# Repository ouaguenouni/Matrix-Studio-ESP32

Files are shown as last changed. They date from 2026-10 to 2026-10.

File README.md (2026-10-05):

# Matrix Studio: ESP32 + Waveshare 64x32

A local browser interface hosted on your ESP32. Send text, resized still images,
pixel drawings, animated GIFs, or browser-streamed scrolling text
to the panel. No cloud account
or separate server is needed. Upload this firmware once; ordinary display updates
then happen over Wi-Fi. Pokémon sprites, the Crystal GIF gallery, cries, and
Bluetooth audio live on the `pokemon` branch.

The five 3D enclosure designs are in
[`cad/enclosure-comparison`](cad/enclosure-comparison/README.md), with an offline
3D viewer, individual STL kits and assembly guides. Digital geometry checks pass;
fit with the actual components still needs a workshop test.

A simpler [two-part frame with an enclosed rear](cad/minimal-frame/README.md)
adds integral ESP32 guides and rear-facing USB-C/DC access. Its
[French workshop guide](cad/minimal-frame/FABLAB-FR.md) covers fit checks and assembly.

## Your hardware

- Classic ESP32-WROOM development board, configured as **esp32dev** in PlatformIO.
- One Waveshare HUB75 panel, 64x32, using the FM6124 driver. The earlier close-up
  appeared to show FM6124H chips. If a previous test sketch works with another driver
  or a different clock phase, carry those settings into `src/main.cpp`.
- Panel powered separately from a regulated 5 V supply with adequate current.
- ESP32 powered by computer USB while uploading; keep its external 5V pin unconnected
  during USB power. Panel and ESP32 grounds must be connected.
- Home Wi-Fi must offer **2.4 GHz**. Your computer/phone can use 5 GHz on the same
  router if the router allows communication between those devices.

This implementation compiles successfully with PlatformIO for **esp32dev** and
passes host-side frame-protocol tests, colour-conversion tests, and JavaScript/Python
syntax checks. USB firmware upload, Wi-Fi provisioning, reconnection, and serial
diagnostic controls have been verified on the connected ESP32. Panel timing is
being compared visually on hardware; the remaining text ghosting is unresolved.
The browser interaction tests pass against simulated endpoints in local Chromium.
Physical colour appearance still needs the viewer's confirmation.

## 1. Install and upload

1. Open this project's root folder in VS Code with the **PlatformIO IDE** extension,
   or use the PlatformIO Core CLI from this folder.
2. Connect the ESP32 by USB. `platformio.ini` selects **esp32dev**, the Arduino
   framework, and pinned versions of the ESP32 platform and display libraries.
   PlatformIO downloads dependencies automatically on the first build.
   `WiFi`, `WebServer`, `Preferences`, and `ESPmDNS` come with the framework.
3. Use PlatformIO's **Build**, **Upload**, and **Monitor** buttons, or run:

   ```bash
   pio run
   pio run --target upload
   pio device monitor
   ```

4. If multiple USB serial devices are connected, select the ESP32 explicitly with
   `pio run --target upload --upload-port /dev/cu.YOUR_PORT` and
   `pio device monitor --port /dev/cu.YOUR_PORT` (use the appropriate port on your OS).
   Run `pio device list` to see available ports.
5. If uploading waits at “Connecting…”, hold BOOT until writing starts, then release it.
6. The serial monitor uses **115200 baud**. Press the board's **EN/RST** button
   to view startup messages.

Hardware and HTTP handling live in `src/main.cpp`; live data and the background
network worker live in `src/live.cpp`. Host-testable parsing, state, and display
rendering live in `include/LiveData.h`, `LiveState.h`, and `Display.h`.
`web/display.json` is the shared font/palette source; `tools/build_display.py`
generates the C++ and JavaScript data tables as part of UI generation. The build regenerates `include/web_ui.h` and `web/preview.html` from the editable
HTML, JavaScript modules, shared display data, and bundled GIF decoder, using
PlatformIO's own Python interpreter.

## 2. Join your home Wi-Fi

On the first boot, Serial Monitor prints something like:

```text
Network: Matrix-a1b2c3
Password: <your device's generated setup password>
Open http://192.168.4.1
```

1. On your phone or computer, join that **Matrix-xxxxxx** Wi-Fi network using the
   printed password. Stay connected even if your phone says “No internet”.
2. Manually open **http://192.168.4.1** in your browser. This is a direct web page,
   not an automatic captive portal.
3. Expand **Wi-Fi connection** if necessary. Enter your home network name and password.
   Use a normal personal/password-based network; enterprise sign-in and captive
   portals are not supported by this starter.
4. Click **Save and connect**. The page and Serial Monitor show the home-network IP.
5. Rejoin your home Wi-Fi and open that IP, such as `http://192.168.1.42`.
   You can also try the unique `.local` hostname printed by Serial Monitor.

Credentials are stored on the ESP32 and reused after restart. They are not placed
in this project or returned by the status API. On the setup session the temporary
network stays active, so you can recover from a mistyped password. It will not be
started on the next boot if the saved home-network connection succeeds within
20 seconds. If joining fails, setup mode returns with the same generated password.

The IP can change after a router restart. Use the `.local` name, check Serial
Monitor, or reserve an IP for the ESP32 in your router. `.local` support varies
by device and network. Guest Wi-Fi/client isolation may block access.

## 3. Use the interface

- **Text:** multiline text, font, pixel size, alignment, foreground/background colours.
  Text is rendered by your browser, including accents supported by its fonts.
  The default is pure white on black with **Sharp text pixels** enabled. Sharp
  mode uses full foreground/background pixels instead of dim antialiased edges,
  including during scrolling. Uncheck it to keep smooth edges.
  The preview shows clipping at the actual 64x32 resolution.
- **Image:** local PNG, JPEG, WebP, BMP, or animated GIF; fit, crop, or stretch.
  Images are resized on your phone/computer, then sent as 4096-byte pixel frames.
  GIFs animate in the preview. Click **Play GIF on panel** to stream the animation,
  or **Send to display** to send a still frame. Playback loops while the page stays
  visible; Stop, Clear, or switching tabs stops uploads.
  The browser decodes transparency, frame disposal and delays, then sends one frame
  at a time. Frame delays have a 40 ms minimum.
- **Draw:** tap or drag on the preview to paint pixels; use the eraser as needed.
- **Global display palette:** Classic, Amber, Neon, Ocean, Mint, or Sunset. Each
  live mode can follow global or use its own palette. Layout and animation are
  separate settings, saved on the ESP32; changing a clock override affects only
  the clock. Text, images, drawings, and GIFs retain their own colours.
- **Weather:** animated icon/temperature or compact temperature/condition/city.
  Choose network location or search for a city. Real zero temperatures remain
  valid; missing data shows `--`. Long city names scroll slowly.
- **BOOT button:** a short press steps through clock, weather, and configured
  YouTube. EN/RST still restarts the board.
- **Clock:** large digits with a seconds indicator, or time and date, using French
  network time. Unsynchronised time shows `--:--`.
- **YouTube:** Cosmic Hippo Sounds subscribers, total views, and video count.
  Choose rotating statistics (one card every five seconds) or subscriber focus.
  Enable YouTube Data API v3 in Google Cloud and save a key on the panel. Website
  referrer restrictions do not work with direct ESP32 requests. You may restrict
  API access to YouTube Data API v3. A key in gitignored `config.conf`
  (`youtube_api_key=...`) seeds the device only when no key is already saved.
- **Animation:** Full, Subtle (default), or Off for each live mode. Off stops
  decorative motion and label scrolling, while measurements, time, and rotating
  statistic cards still update. Browser reduced-motion preference disables
  preview animation without changing the panel setting.
- **Startup and refresh:** restores the last selected live mode, including an
  explicit stopped mode, and all appearance settings. Weather and configured
  YouTube data load once Wi-Fi connects, even while the clock is showing. Refresh
  happens every ten minutes, with one-minute retries and manual refresh buttons.
  A background worker keeps the display, BOOT button, and web controls responsive.
- **Service status:** loading, ready, stale, unconfigured, or error, with the age of
  the last successful update and a useful error message. A small amber corner dot
  marks stale LED data. Failed refreshes retain the last successful values in RAM;
  after power loss, data must load again. Missing data shows `LOADING`, `ADD KEY`,
  or `CHECK WEB`, rather than invented zeroes.
- **Send to display:** commits the preview. Editing alone does not update the panel.
- **Clear:** clears the preview; then press Send to clear the physical panel.
- **Brightness:** changes the physical panel immediately; initial value is 30/255.
- **Scrolling:** sends approximately eight frames per second, subject to Wi-Fi speed.
  Keep the browser page visible and awake. It stops if you leave the tab or close it.

The last sent frame remains while the ESP32 is powered, even if the browser closes.
Uploaded pixel frames and brightness are **not** restored after power loss. Wi-Fi,
live mode, location, API key, and appearance settings are restored.
Videos, saved playlists, and remote control from outside your network
are extension points, not included features. This interface has no user login;
clients on the same LAN or password-protected setup network can control it.

## Pin mapping

The table records the reported ribbon-wire connections and corrected firmware
LED channels. The direct RGB test rendered red, blue, green, so firmware swaps
green and blue on both panel halves. Wire colours identify the ribbon conductors;
they do not identify LED colours.

| Wire number | Wire colour | Firmware channel/signal | ESP32 printed label |
|---|---|---|---|
| 1 | Brown — outer edge | R1 | G25 |
| 2 | Red | B1 | G26 |
| 3 | Orange | G1 | G27 |
| 4 | Yellow | GND | GND |
| 5 | Green | R2 | G14 |
| 6 | Blue | B2 | G12 |
| 7 | Purple | G2 | G13 |
| 8 | Grey | GND | GND |
| 9 | White | A | G23 |
| 10 | Black | B | G19 |
| 11 | Brown — second occurrence | C | G5 |
| 12 | Red — second occurrence | D | G17 |
| 13 | Orange — second occurrence | CLK | G16 |
| 14 | Yellow — second occurrence | LAT/STB | G4 |
| 15 | Green — second occurrence | OE | G15 |
| 16 | Blue — other outer edge | GND | GND |

The 64x32 panel does not use E. All 5 V power stays on the separate power connector;
none of the HUB75 signal wires connects to the ESP32 5V or 3V3 pins.

## Develop your own interface

The architecture is browser rendering → RGB565 frame upload → ESP32 DMA display.
You can replace the browser editor, generate a clock/dashboard elsewhere, or use
the included Python image sender without changing how the panel is wired.

| Endpoint | Method | Input | Effect |
|---|---|---|---|
| `/` | GET | None | Browser interface |
| `/api/status` | GET | None | Network, dimensions, brightness, frame count, free heap |
| `/api/frame` | POST | One multipart file named `frame` | Atomically replace all pixels |
| `/api/brightness` | POST | URL-encoded `value=0..255` | Set brightness |
| `/api/wifi` | POST | URL-encoded `ssid` and `password` | Save credentials and connect |
| `/api/live` | POST | URL-encoded fields below | Live modes, saved appearance, and refresh |

Live control fields (all optional, validated before applying):

- `mode=clock|weather|youtube|off|save`: select a mode, freeze the current frame,
  or save settings without switching. Omitting mode also leaves it unchanged.
- `theme=classic|amber|neon|ocean|mint|sunset`: global palette. The legacy `theme`
  field remains supported. The previous saved numeric theme migrates automatically.
- `target=clock|weather|youtube` with `palette=global|<palette>`,
  `layout=large|date` (clock), `icon|detail` (weather), or `rotate|subscribers`
  (YouTube), and/or `motion=off|subtle|full`: independent per-mode appearance.
- `city=<name>` or `locate=1`: queue location lookup and weather refresh. Lookup
  completion and errors appear in status; HTTP success means accepted, not fetched.
- `key=<YouTube API key>`: persist a key and load statistics; keys are never returned.
- `refresh=weather|youtube`: request a refresh without changing the display mode.

`/api/status` keeps existing fields and adds `appearance` (`global`, plus a
`palette`, `layout`, and `motion` object per live mode), `savedMode`, `clockSynced`,
`liveTick` (milliseconds since mode selection), and `services.weather` /
`services.youtube`. Each service reports `state`, `refreshing`, `ageSeconds`
(null before first success), and `message`. Existing `temp`, `kind`, `channel`,
`subs`, `views`, and `videos` appear only after successful validated responses.
`weatherCode` contains the validated WMO code. Counts remain formatted strings;
hidden subscribers use `--`. `youtube` means a key is configured, not that a fetch
has succeeded. `live` reports `off` when manual frame uploads hold live rendering.

All POST requests require the header `X-Matrix-Control: 1`. It limits accidental
cross-site browser requests; it is **not** an authentication credential. CORS is
not enabled. Serve browser extensions from this device's page or use a backend
proxy on your own application when hosting an interface separately.

Frame format: exactly **4096 bytes**, 64x32 pixels in row order, top-left first.
Each pixel is RGB565 with the low byte first: red uses bits 11–15, green 5–10,
blue 0–4. Incomplete/oversized uploads are rejected without replacing the display.

```bash
curl -H 'X-Matrix-Control: 1' \
  -F 'frame=@frame.rgb565;type=application/octet-stream' \
  http://192.168.1.42/api/frame

curl -H 'X-Matrix-Control: 1' -d 'value=30' \
  http://192.168.1.42/api/brightness

python3 -m pip install Pillow
python3 tools/send_image.py http://192.168.1.42 photo.png
```

To edit the embedded interface, modify `web/interface.html`, `web/codec.mjs`,
`web/gif.mjs`, `web/gif-player.js`, `web/weather.mjs`, `web/clock.mjs`, or `web/youtube.mjs`,
then build and upload the firmware again. PlatformIO regenerates the embedded UI
automatically; you can also run `python3 tools/build_ui.py` manually.
`web/preview.html` is the generated UI for local inspection; a normal local preview
does not control hardware because it has no ESP32 server behind it.

## Verification and troubleshooting

After `pio run` installs pinned dependencies, run `npm run test:firmware` for
actual firmware JSON parsing, scheduling, settings migration, pixel renderer
parity (972 cases), frame protocol, and colour-table checks. Run `npm test` for
the browser and JavaScript checks.

Run `node tests/codec_test.mjs`, `node tests/modules_test.mjs`, and compile/run `tests/frame_protocol_test.cpp` with
a standard C++ compiler. `tests/browser_test.cjs` runs the browser interface
against simulated endpoints using Playwright. These do not replace hardware testing.
The small MIT-licensed omggif decoder is bundled locally with its license retained
in `web/vendor/`.

The panel runs at six-bit colour depth. `platformio.ini` also defines
`PIXEL_COLOR_DEPTH_BITS=6` when compiling the HUB75 library, so its brightness
lookup table matches the six DMA bitplanes. An eight-bit table with only six
bitplanes discards the upper bits and wraps intermediate colours; full white
can still look correct. The firmware checks the configured depth at compile time.
The regression test exercises the pinned library's actual table:

```bash
c++ -std=c++11 -Wall -Wextra -Werror -DPIXEL_COLOR_DEPTH_BITS=6 \
  -I '.pio/libdeps/esp32dev/ESP32 HUB75 LED MATRIX PANEL DMA Display/src' \
  tests/panel_colour_test.cpp -o /tmp/matrix-panel-colour-test
/tmp/matrix-panel-colour-test
```

On hardware, first verify the previous RGB test sketch works. After uploading
this project, use **Image → Preview a colour test → Send to display**. Then verify
text, brightness, Wi-Fi reconnect after a reset, and preservation of the last frame
after closing your browser. Send at low brightness for the first tests.

To bypass browser rendering and frame uploads, open the serial monitor at 115200
baud and send uppercase `T`. The firmware displays red, green, and blue vertical
bands on the top 24 rows, with a white strip on the bottom 8 rows, using RGB888
directly. Send normal content from the web
interface to replace the test. If green and blue are black in this test too, check
the corresponding signal wires and panel hardware: G1 → GPIO27, B1 → GPIO26,
G2 → GPIO13, B2 → GPIO12. Turn off power before reseating wires.

Send uppercase `W` over serial to fill the entire panel with white at the current
brightness. Send normal content from the web interface to replace the white test.
Send uppercase `G` for eight grayscale swatches from black to white on the top
half and cream, pale yellow/red/green/blue/cyan/magenta, and white on the bottom.
This uses direct RGB888 values to check intermediate shades independently of
browser resizing and RGB565 conversion. Judge the colours directly: camera
exposure timing can introduce tints or bands when photographing scanned LEDs.
Send uppercase `V` for red, green, blue, magenta, purple, dark purple, lavender,
and white columns. The top half uses direct RGB888, the bottom RGB565 as used
by browser uploads. Magenta, purple and dark purple have zero green input.
In the browser's Image tab, **Preview a purple test → Send to display** sends
the same colours through the actual browser/upload path. Compare directly with
your eyes. Differences between panel halves can also indicate separate upper
and lower signal wiring, so they are not proof of an encoding fault by themselves.
Send uppercase `H` for a static white `Hello` on a black background. This is drawn
once using the on-device font, without browser rendering or continuous frame uploads.
Startup now uses profile **N**, the best of the latest visual comparison: 4 MHz,
clock phase false, four blanking clocks, and the weakest clock drive (level 0).
Other panel signals retain the library's drive level 3. The observed ranking was
K, then I; L and M were clearly worse. N subsequently looked best when compared
with K, O and P, and remained best against the slower Q, R and S trials. N is the
selected operating setting; complete removal of shifted ghosting is unconfirmed.
Send uppercase `C` over serial to switch between clock drive levels 0 and 3 while
the same image stays displayed. Reboot restores profile N.

Send uppercase `S` to compare timing profiles A–S. Each profile displays its letter,
two white `Hello` lines, and a thin vertical white line for 12 seconds; the sequence
repeats every 228 seconds. Brightness stays constant so the timing comparisons
use the same content and intensity. Ignore the brief transition between profiles.
Report the letter with the fewest ghost pixels, checking both halves of the panel.
Serial commands: `P` pauses/resumes, `N` advances, and `X` stops and restores the
settings used before the sweep. Sending normal content, changing brightness,
or using `T`, `W`, `G`, `V`, `H`, or `C` also stops the sweep and restores those settings.

Send uppercase `F` for the focused **N → Q → R → S** comparison (12 seconds per
test, 48 seconds per cycle). This retains N's weakest clock drive, phase false,
four blanking clocks and strong non-clock signals, comparing 4, 2, 1 and 0.5 MHz.
The slowest profile is eight times slower than N. These trials intentionally
lower scan refresh too; compare the shifted copies separately from whole-panel
flicker. Serial logs include estimated scan refresh, scaled from startup's DMA
calculation. The estimate is not an oscilloscope measurement.
The same pause, next, and stop controls apply.

| Test | Clock output | Clock phase | Blanking clocks | Clock drive level |
|---|---|---|---|---|
| A | 10 MHz | false | 4 | 2 (medium) |
| B | 5 MHz | false | 4 | 2 (medium) |
| C | 10 MHz | true | 4 | 2 (medium) |
| D | 5 MHz | true | 4 | 2 (medium) |
| E | 10 MHz | false | 2 | 2 (medium) |
| F | 5 MHz | false | 2 | 2 (medium) |
| G | 10 MHz | true | 2 | 2 (medium) |
| H | 5 MHz | true | 2 | 2 (medium) |
| I | 5 MHz | false | 4 | 1 (lower) |
| J | 5 MHz | false | 4 | 3 (maximum) |
| K | 5 MHz | false | 4 | 0 (weakest) |
| L | 5 MHz | false | 4 | 1 (lower) |
| M | 5 MHz | false | 4 | 1 (lower) |
| N | 4 MHz | false | 4 | 0 (weakest) |
| O | 5 MHz | true | 4 | 0 (weakest) |
| P | 4 MHz | true | 4 | 0 (weakest) |
| Q | 2 MHz | false | 4 | 0 (weakest) |
| R | 1 MHz | false | 4 | 0 (weakest) |
| S | 0.5 MHz | false | 4 | 0 (weakest) |

Profiles A–K and N–S leave non-clock signals at the library's drive level 3. L lowers only
LAT and OE to level 1; M lowers all non-clock data/address/control signals to
level 1. Each profile restores other signals explicitly so the previous profile
does not influence the next comparison. All profiles use the same brightness.

The sweep's clock-divider override targets the classic ESP32 and pinned HUB75
library. This library's nominal `HZ_8M` configuration uses an actual 10 MHz clock
on the classic ESP32 (80 MHz / divider 4 / 2). The 5 MHz profiles use divider 8;
4 MHz uses divider 10; 2, 1 and 0.5 MHz use dividers 20, 40 and 80 respectively.
The slower profiles also lower scan refresh, so report any
whole-panel flicker separately from shifted ghost pixels.
Startup applies profile N after the library initializes DMA, and its DMA refresh
calculation uses the matching 4 MHz clock. Sweep changes are temporary and do not
rewrite saved Wi-Fi credentials or the startup configuration. Reboot exits the
sweep. Profile labels describe the clock output; the calculated refresh value
describes startup profile N and is not updated by temporary sweep overrides.

- Blank panel with a reachable web page: check input connector, ground, pin mapping,
  and driver selection. Copy any successful settings from your earlier test sketch.
- Colours swapped: first confirm the wiring. Some panel variants need a software
  swap of green and blue pins, but do not change these blindly.
- Shifted pixels/ghosting: the firmware currently uses `config.clkphase = false;`,
  a 4 MHz clock, four clock cycles of latch blanking, and the weakest clock drive.
  Use the serial timing comparisons to evaluate other settings. Short, secure
  signal wires and a shared ground remain important if ghost pixels persist.
- Resets/flicker during Wi-Fi use: verify stable power and short, secure signal wires.
  Some panel variants need a proper 3.3 V to 5 V logic buffer for reliable operation.
- Panel initialization fails: read Serial Monitor, check library/board selection,
  and temporarily try `config.double_buff = false;` if memory allocation is failing
  (frame replacement may then visibly tear).
- Wi-Fi setup fails: check exact SSID/password, 2.4 GHz availability, and personal
  network security. Retry through the setup network; no new firmware upload is needed.

## References

- Espressif Wi-Fi API: https://docs.espressif.com/projects/arduino-esp32/en/latest/api/wifi.html
- Espressif WebServer example: https://github.com/espressif/arduino-esp32/tree/master/libraries/WebServer/examples/HelloServer
- HUB75 library: https://github.com/mrcodetastic/ESP32-HUB75-MatrixPanel-DMA
- Waveshare panel: https://docs.waveshare.com/RGB-Matrix-Px-64x32
- GIF decoder (MIT): https://github.com/deanm/omggif

Updated 2026-10-04. No real Wi-Fi credentials are included.

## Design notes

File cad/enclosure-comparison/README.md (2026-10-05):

# Five enclosure designs — INGE / AFTER HOURS

The five digital prototype kits are complete: editable OpenSCAD, separate STL
parts, acrylic outlines, assembled/exploded previews, an offline interactive
viewer, quantities, and assembly instructions. Revision 3, 5 October 2026.
**Physical hardware fit is still unverified.** Fit-test the small parts with the
actual panel, ESP32 and cables before printing a complete case.

Open [viewer.html](viewer.html) in a desktop browser. It works without internet;
use the five tabs, Front/Rear, Open back and Exploded controls. The viewer embeds
actual STL meshes; the panel and PCB are nominal component envelopes. Preview
LED artwork is illustrative. [comparison.png](comparison.png) shows all five.

| Design | Case width × height × depth, mm | Acrylic, mm | Cable tray height | Estimated stored cable* |
| --- | --- | --- | --- | --- |
| [Line](kits/01-line.zip) | 190 × 110 × 94.5 | Cut 164 × 84 × 1 | 14 mm | 0.2 m |
| [Orbit](kits/02-orbit.zip) | 202 × 122 × 96.5 | Cut 164 × 84 × 1 | 20 mm | 0.4 m |
| [Gallery](kits/03-gallery.zip) | 206 × 156 × 96.5 | Full 180 × 130 × 1 | 20 mm | 0.4 m |
| [Vault](kits/04-vault.zip) | 206 × 156 × 122.5 | Full 180 × 130 × 1 | 40 mm | 1.0 m |
| [Console](kits/05-console.zip) | 202 × 122 × 108.5 | Cut 164 × 84 × 1 | 30 mm | 0.8 m |

Depth includes the rear port plate, excludes screw heads and cradle lips.
Feet add 4 mm below the case; their lips extend beyond the front/rear faces.
*One bundle with 6 mm effective diameter; estimate excludes service tails and
assumes a 0.2 m oval per turn. It is a planning allowance, not a measured cable fit.
Vault has the largest wiring compartment; Line is the smallest enclosure.

The confirmed component list is **one panel, one ESP32, acrylic, and wiring**.
The power adapter stays outside. No speaker or extra electronics are assumed.
The default rear plate passes the existing power and USB leads through two
separate openings, so a USB extension is not required. The optional
`ports_usb_c.stl` is only for a separately selected round panel-mount USB adapter.

- [Print and assembly guide](PRINT-GUIDE.md): quantities, fasteners and fit steps.
- [French workshop sheet](FABLAB-FR.md): handoff for the fablab.
- [Audit](AUDIT.md): corrections, evidence and unresolved physical measurements.
- [Validation report](validation.json): mesh, assembly and clearance results.
- [All five kits and viewer](five-enclosure-kits.zip): complete portable handoff.

The older `cad/inge-after-hours` folder is the first single-case prototype.
Use this comparison family for these five designs; its acrylic is 1 mm, whereas
the older model assumed 2 mm.

## Reproduce or adjust

Use Python 3.11+ and OpenSCAD. In an isolated Python environment:

```sh
python3 -m venv /tmp/matrix-cad-venv
/tmp/matrix-cad-venv/bin/pip install -r cad/enclosure-comparison/requirements.txt
/tmp/matrix-cad-venv/bin/python cad/enclosure-comparison/build.py
/tmp/matrix-cad-venv/bin/python cad/enclosure-comparison/validate.py
/tmp/matrix-cad-venv/bin/python cad/enclosure-comparison/render.py
/tmp/matrix-cad-venv/bin/python cad/enclosure-comparison/make_viewer.py
/tmp/matrix-cad-venv/bin/python cad/enclosure-comparison/package_kits.py
```

Set `OPENSCAD='/path/to/openscad'` if it is not on PATH. A portable official Node
WASM build also works: `OPENSCAD='node /path/to/openscad.js'`. Exports in this
revision used OpenSCAD 2026.10.03. Pinned Python dependencies record the validation
environment; use compatible versions if a wheel is unavailable for your Python.

`build.py --help` lists measured component overrides, for example
`--pcb-length 58 --pcb-width 29 --pcb-hole-length 52 --pcb-hole-width 23`.
Those numbers are current provisional defaults, not measurements of your board.
OpenSCAD `family.scad` also exposes these parameters. After changing them, rerun
all five steps: the manifest, meshes, visualizations and checks must agree.
The mounting slots accept 30–64 mm hole spacing along the board and 0–32 mm
across it; check actual board edge clearance and screw size separately.

Export individual parts, never an assembled or exploded mesh as one print.
All parts fit the assumed 220 × 220 × 250 mm build volume with 5 mm brim allowance
in the supplied orientation. Machine-specific slicing and print settings still
belong to the workshop. No machine G-code is distributed.

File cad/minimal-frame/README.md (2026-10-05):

# Minimal frame — enclosed rear, two printed parts

A close-fitting frame for the 160 × 80 mm display, with a ventilated rear shell.
The ESP32's USB-C socket and the existing DC power adapter both face backwards.
The shell incorporates the PCB guides and adapter cradle. Three small cable ties
retain the hardware; no separate PCB carrier, feet, port plate or USB extension
is required. The mains power supply stays outside.

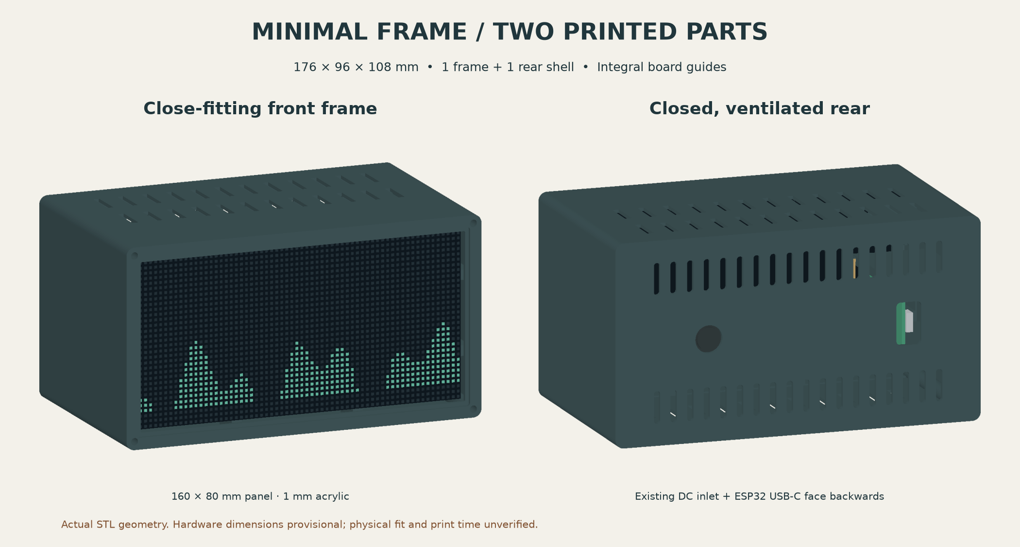
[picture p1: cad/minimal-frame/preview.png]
Front and rear views of the exported enclosure


**Prototype: digital geometry checked; physical hardware fit remains unverified.**
The nominal panel dimensions come from the existing project references. The PCB,
socket positions and DC adapter dimensions below are provisional, not measured
from the photographs. Check them before printing the full shell.

| Installed print | Quantity | Size, mm | Print orientation already in STL |
| --- | --- | --- | --- |
| [frame.stl](stl/frame.stl) | 1 | 176 × 96 × 23.3 | Rear mounting ears on the bed |
| [rear.stl](stl/rear.stl) | 1 | 176 × 96 × 84.7 | Outer back face on the bed |

Assembled size: **176 × 96 × 108 mm**, excluding screw heads and connected plugs.
The panel pocket has 0.35 mm clearance on each side. Acrylic: **164 × 84 × 1 mm**,
with 1 mm corner radii. Its front recess has 0.3 mm clearance per side.

The ESP32 stands on edge so its own USB socket points directly backwards.
Its provisional 58 mm length, the panel and room for connected wiring determine
the depth. There is no six-hour print-time guarantee. The two installed parts
contain **165.5 cm³ of solid geometry**, approximately half the solid volume of
the earlier Line design with all its installed parts. This is a geometry
comparison, not a slicer filament or time prediction. Thin walls, integral
fixtures and two print jobs keep fabrication straightforward. With two suitable
printers, print the frame and shell simultaneously; elapsed printing time is the
longer job. Both also fit together on a nominal 220 × 220 mm bed with suitable
placement (186 × 212 mm including 5 mm outer brim and 10 mm part spacing).

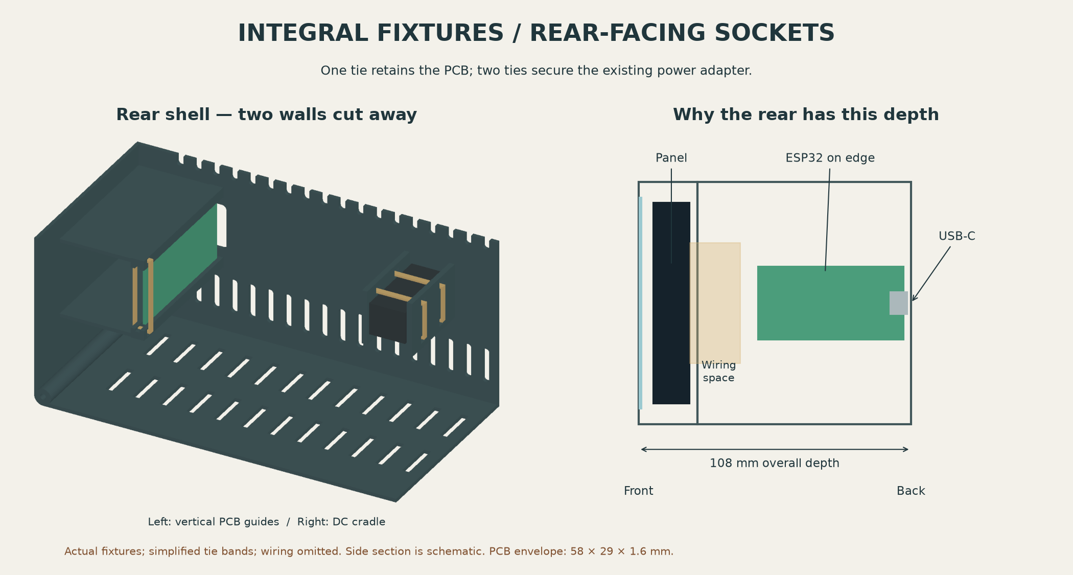
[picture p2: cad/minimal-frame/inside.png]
Internal fixtures and depth explanation


## Files and assembly

Use [FABLAB-FR.md](FABLAB-FR.md) for the French workshop instructions and hardware
list. [minimal-frame.zip](minimal-frame.zip) contains the complete kit, including
the editable source, two main STLs, optional fit gauges, acrylic cutting outline,
previews and validation report.

1. Check the panel fit with [fit_corner.stl](fit-tests/fit_corner.stl) and PCB
   edges with [board_gauge.stl](fit-tests/board_gauge.stl). These are test pieces,
   not installed components. Measure the DC adapter and connector positions.
2. Load the panel through the front. Attach its four rear M3 inserts to the
   integral 3 mm mounting ears, choosing screw engagement for the actual inserts.
3. Seat the acrylic from the front. Small removable adhesive strips on the ledge
   retain it. This avoids a third printed retaining ring.
4. Slide the ESP32 USB-end first into the rear shell's grooves, component face
   toward the outer side wall. Pass a 2.5 mm cable tie through the closed windows
   above its far end. Seat and strap the DC adapter with two more ties through
   the cradle's paired windows. Leave the socket mouths and terminals clear.
5. Connect the existing wiring, retain a service loop, and close the two halves
   with four M3 × 30 mm screws inserted from the front corners. Check plug access
   and connector retention before powering the display.

## Adjust and rebuild

Edit the dimensions at the top of [model.scad](model.scad). `part="assembly"`
previews the assembly; `part="exploded"` separates the shell. Other part names
are listed in the source. `reference/` contains hardware envelopes for checking,
**not additional parts to print**. Coordinates: the front is Z=0 and the back
is Z=108 in assembly view; both printable STLs are independently placed on Z=0.

Measure these parameters in particular:

| Parameter | Current assumption | Fit check |
| --- | --- | --- |
| `panel_w`, `panel_h`, `panel_depth` | 160 × 80 × 14.5 mm | Actual panel body and rear insert positions |
| `panel_clearance` | 0.35 mm per side | Sliding fit in the corner sample |
| `pcb_l`, `pcb_w`, `pcb_t` | 58 × 29 × 1.6 mm | Bare PCB; includes enough clear edge for grooves |
| `pcb_slot` | 2.2 mm | Actual board thickness and printer tolerance |
| `pcb_stop` | 2.8 mm behind the back face | Actual USB overhang and recess; assumed overhang 1.5 mm |
| `usb_open_x`, `usb_open_y` | 12 × 20 mm | Actual plug body; modeled plug envelope 10 × 14 mm |
| `power_l`, `power_w`, `power_h` | 35 × 16 × 14 mm | Existing barrel-to-terminal adapter body |
| `power_open_d` | 13 mm | Adapter nose and plug; modeled nose Ø11, plug Ø12 mm |
| `rear_z` | 108 mm | Board guides and actual connected wire clearance |

The guides engage only 0.8 mm of each long PCB edge. Check that edge for solder,
headers and components. Changes to USB position or the power adapter's shape may
require editing the corresponding mock and fixture modules as well as the values.
Panel mounting centers are fixed at 125 × 65 mm; alter the mounting ears and
validation if the actual panel differs.

With OpenSCAD available and Python dependencies from `requirements.txt`:

```sh
python3 -m pip install -r requirements.txt
python3 build.py
python3 validate.py
python3 render.py
python3 package.py
```

Run from this directory. `OPENSCAD` may specify a native executable or a Node
WASM command, e.g. `OPENSCAD="node /path/to/openscad.js"`. This export was made
using OpenSCAD 2026.10.03 (Manifold). The build removes collapsed zero-area STL
faces caused by export rounding; it does not fill holes. The manifest records
source/export hashes and the number of removed faces.

`validation.json` records connected watertight solids, bed placement, assembly
collisions, panel/PCB insertion paths, tie paths, plug and wiring envelopes, and
screw-head clearance. These checks do not establish real-world fit, strength,
thermal behavior or print duration. Regenerate and validate after any dimension
change; use the workshop's slicer profile for the actual machines.

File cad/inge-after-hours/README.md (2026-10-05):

# INGE / AFTER HOURS — enclosure prototype

**Dimensioned, editable concept. Do not print the complete gift enclosure yet.**
The STL files are labelled prototypes because the photographs establish the panel
family and USB connector, but do not provide the mechanical measurements needed
for a reliable fit. Print the small `coupon.stl` first after selecting connectors. The bought QWORK acrylic
sheets are 180 × 130 mm; a 164 × 84 mm window must be cut from one sheet.

## Files

- `enclosure.scad`: editable parametric source; choose `part` in OpenSCAD Customizer.
- `prototype-stl/`: individual printable meshes for review/fit testing, not approved hardware fit.
- `acrylic-front-164x84.svg`: full-size cutting outline for the purchased acrylic.
- `validate_and_render.py`: checks STL topology/size and renders the actual meshes.
- `validation.json` / `prototype-overview.png`: geometry results and exploded view.
- `assembled-preview.png`: front/rear assembled views; panel face is illustrative.
- `FABLAB-FR.md`: French handoff sheet for the workshop, including fit checks.

The user confirmed that the complete printed enclosure replaces the picture frame.
The rear cover carries an engraved INGE / AFTER HOURS inscription; the removable
connector plate is engraved POWER and USB.

## Evidence from the five photographs

All five `pictures/IMG_20261005_*.jpg` were inspected. The rear moulding reads
**P2.5-1 / 80×160**, consistent with Waveshare's P2.5 panel dimensions. The user identifies the controller as **ESP32 NodeMCU WiFi Bluetooth Module
ESP32 WROOM 32 Development Board**. This family name does not specify a PCB
revision or mechanical drawing. The photographed ESP32
has a **USB-C** socket, four PCB corner holes, and BOOT/EN buttons. The photos show
an external wall adapter and barrel-jack-to-terminal-block adapter. Its oblique
label appears **5.0 V / 3.0 A / 15.0 W**; verify on the actual label. The barrel's
inner/outer diameter and polarity cannot be determined from these photos.

No ruler, depth measurement, exact board model, hole centres or connector drawings
are visible. A PCB scale inferred from fingers or perspective is not reliable.
The official panel drawing is available as DWG from Waveshare, but was not parsed
into this model; the panel retention scheme therefore avoids guessing its holes.

## Parts and mechanical layout

| Part | Quantity | Purpose |
| --- | ---: | --- |
| shell | 1 | Recessed front rim, panel seat, clip towers, lid bosses, cable anchors and vents |
| front_spacer | 1 | Separates the acrylic pocket from the LED face; printed flat |
| acrylic (not printed) | 1 | 164 × 84 mm laser-cut window from the purchased QWORK sheet |
| lid | 1 | Removable rear cover; separate vents, carrier mount and connector-plate opening |
| ports | 1 | Replaceable plate for power jack and a USB-C data extension |
| carrier | 1 | Controller tray with stand-offs; board dimensions/hole spacing provisional |
| clip | 4 | Retain panel structural edges without using unmeasured panel holes |
| stand | 2 | 10-degree desk wedges; add non-slip pads and check stability with connected cables |
| coupon | 1 | Power/USB cutout and 2.6/2.8/3.0/3.2 mm hole fit tests |

Default body: **182.8 × 102.8 × 60 mm**, plus 3 mm rear lid and local 3 mm port
plate. This leaves generous rear wiring room; reduce depth only after checking
plugged-in connectors and ribbon bends. Front overlap is 0.6 mm per edge: verify
it misses every LED. Panel clips touch only the structural rear edge and should
not load the PCB or solder joints. Rear display depth defaults to 15 mm solely
for modelling; this is unverified.

The controller is carried on the inside of the lid, with component side facing
into the enclosure. Add four board fasteners with suitable nuts, and two carrier
fasteners/nuts through the lid. The USB socket is reached through a short,
**data-capable** panel-mount USB-C extension. This is a proposed additional part,
not something shown in the photographs. Select its actual flange drawing and
cable bend before printing the port plate. The provisional 8 mm power cutout is
a panel jack's *mounting* diameter, not the existing barrel plug's diameter.

The lower open channel is reserved for the power pair. Its shelf is 128 mm long,
with an inner retaining lip; the six original tie anchors remain. Route the HUB75
ribbon along the upper perimeter without sharp folds and use the upper anchors
for cable ties, rather than trying to squeeze the ribbon into the power channel.
Keep the antenna clear and leave a service loop to remove the rear lid. Tie tunnels are
small bridges; check the slicer bridge preview. Screw bosses have 2.6 mm pilot
holes as a starting point for pre-tapping M3 after coupon testing. These are not
heat-set-insert pockets. Do not force a screw into a printed undersized hole.

BOOT/EN remain accessible by removing the lid; there is no external plunger in
this prototype. If direct daily BOOT access is required, measure the switch
locations and add a separate non-preloaded plunger before the final print.

## Measurements to replace before final export

`panel_depth`, `pcb_l`, `pcb_w`, `pcb_hole_l`, `pcb_hole_w`, `pcb_hole_d`,
`pcb_standoff`, `power_mount_d`, `usb_open_w`, `usb_open_h`, `usb_mount_pitch`,
`usb_mount_d` and the case depth/cable-clearance assumptions need physical checks.
Confirm 160×80 mm panel outline, its edge-retention surfaces and plugged-in depth.

The selected printer/filament may require different mating/fastener allowances.
Parameters `fit` and `panel_clearance` document separate purposes: the current
cover is flat screw-on and does not use a friction-fit mating lip, so `fit` is
reserved for a future locating lip. No shrink compensation is hidden in the STLs.

## Printing and assembly

Start with a **0.4 mm nozzle, 0.2 mm layers, four perimeters, 15–20% infill**, PETG
and the fablab's validated machine/filament profile. These are suggested settings,
not a sliced/bench-tested profile. Print shell front-down, lid/plate flat,
carrier base-down, clips flat, and wedges base-down. The shell front-down has a
continuous frame contact ring; add a brim if the fablab recommends it. Inspect
slicer supports under elevated screw bosses/anchor bridges; local support may
be needed. Do not send machine-specific G-code until the machine is confirmed.

1. Fit-test the coupon with real connectors and screws; revise dimensions.
2. Test board carrier and one clip/seat region with real hardware.
3. Print final parts only after confirming fit. Retain the panel gently with
   four clips; do not exceed the panel's measured structural height.
4. Secure connector bodies, strain relief and board; route cables through
   anchors with a service loop. Insulate all exposed electrical connections.
5. Follow the confirmed power procedure below; check USB upload with lid open.
6. Close the lid, check Wi-Fi/controls, cable pulls and desk stability, and test
   temperature under sustained usage before wrapping the gift.

Fastener lengths depend on actual panel depth, PCB and connector flange thickness.
Choose lengths at assembly to prevent bottoming out or contacting electronics;
no unverified universal screw-length shopping list is provided.

## Power is a separate unresolved design decision

Keep the mains wall adapter external. The existing README says external ESP32
5 V must stay disconnected during USB powering. The photographs show attached
wires but do not establish a protected power path. **Do not assume simultaneous
external 5 V and computer USB are safe.** If one everyday power inlet must feed
both panel and ESP32, identify the exact board and have its supply selection or
isolation arrangement verified. The enclosure openings do not solve this circuit.

## Export/reproduce

OpenSCAD desktop can render each part and export STL. For scripted generation:

```sh
openscad --export-format binstl -o prototype-stl/shell.stl \
  -D 'part="shell"' -D allow_prototype_export=true enclosure.scad
```

`allow_prototype_export=true` is an explicit acknowledgement of unknown dimensions.
Set `verified_dimensions=true` only after measuring and fit-testing; changing the
flag itself does not verify a design. Other parts use the same command and their
part names. `assembly` and `exploded` are review views, not single printable pieces.

Validation/render dependencies are `trimesh`, `scipy` and `matplotlib`:

```sh
python3 validate_and_render.py
```

Meshes were exported using official OpenSCAD 2026.10.03 WebAssembly Node build
in `/tmp`; no CAD application was installed system-wide. Geometry checks cannot
prove dimensional fit, material behaviour, electrical suitability or print quality.

## Toulouse fablab research — 5 October 2026

**Recommendation: Artilect**, prioritising guided access before Inge's 9 October
birthday. Its posted public schedule includes Tuesday–Friday 08:30–19:00 and
Saturday 10:00–18:00. Machine brand alone cannot establish finish quality; request
a calibrated PETG profile and inspect a small sample first. **Artilect** officially lists
Ender 3 machines with 220×220×250 mm beds, PETG support, and a CR-10 S5 with a
500 mm cube. The current enclosure fits a 220 mm bed with a modest brim; printing
the large parts separately avoids overfilling the bed. Artilect asks users to
start with an initiation and book machines. Confirm a slot before the birthday;
no reservation has been made.

**RoseLab** confirms a 3D lab but its public lab page did not identify exact
available machines/usable build volume during this review. **CampusFab** lists
Bambu P1S and X1C machines and requires training before autonomous access. Confirm
current machine availability and staff-selected slicing settings. CampusFab's
fresh homepage did not display a forthcoming opening session during this check;
its indexed machine list is not confirmation of bookable access before 9 October.
No venue was contacted and no booking or payment has been made.

## Sources

- [Waveshare specifications](https://www.waveshare.com/RGB-Matrix-P2.5-64x32.htm)
- [Official P2.5 DWG](https://files.waveshare.com/wiki/RGB-Matrix-P2.5-64x32/RGB-Matrix-P2.5-64x32-2D.dwg)
- [OpenSCAD official downloads](https://openscad.org/downloads.html)
- [Artilect machines and printing process](https://www.artilect.fr/impression-3d)
- [RoseLab labs](https://roselab.eu/les-labs/)
- [CampusFab equipment and access](https://campusfab.net/)

## Supplied product links

- Panel: https://www.amazon.fr/dp/B0BQYDLHY9 — supplied by the user; matches the
  photographed Waveshare P2.5 family. The 160 × 80 mm outline is supported by the
  manufacturer specification and the moulded panel marking.
- Controller: https://www.amazon.fr/dp/B0DB8F8MKH?th=1 — supplied by the user.
  User-provided product title: **ESP32 NodeMCU WiFi Bluetooth Module ESP32 WROOM 32 Development Board**.
  Listing contents could not be verified; browser access was denied. USB-C and
  four mounting holes are confirmed by the actual board photograph, but its
  precise outline and hole coordinates remain provisional.

The editable model deliberately does not claim measured fit from an ASIN alone.
The workshop can complete the remaining measurements and fit tests with the
physical hardware, using FABLAB-FR.md; the user need not guess these dimensions.

## Acrylic front — purchased QWORK sheets

User-supplied product: **QWORK 10 × Transparent Acrylic Sheets, 13 × 18 cm**.
Sheet stock is 180 × 130 mm; the CAD window is **164 × 84 mm**, with 1 mm corner
radii. `acrylic-front-164x84.svg` is a 1:1 millimetre laser-cut outline. Cut the
sheet; it does not fit this compact case at its full purchased size. Confirm
the material from the packaging before the workshop chooses its cutting process.
The SVG page includes a 1 mm margin: its page is 166 × 86 mm, but the actual
cut path is 164 × 84 mm. Import at 100%; do not resize the page to the cut size.

Thickness was not given in the product title. `acrylic_thickness=2` is a **CAD
starting assumption**, not a claim about these sheets. Measure the stock at the
workshop and regenerate the shell before final printing. `acrylic_clearance=0.3`
provides per-side fit allowance and a thickness allowance for a thin compliant
edge pad; select/test the actual pad with the actual sheet so it cannot rattle.

Front-to-back stack: printed front rim → acrylic sheet in a locating pocket →
printed perimeter spacer → LED panel → retaining clips. The nominal 1.5 mm spacer
keeps the sheet away from the LEDs. Check actual LED height and border clearance
with the real panel; adjust `led_gap` if needed. Remove the panel/retainers from
the rear to replace the acrylic; no permanent glue is required. Clips must bear
on the panel's structural frame and must not over-compress the acrylic.

The clear sheet protects the front; optical diffusion is not assumed. The preview
uses an illustrative tint to show its location, not a prediction of transmission.
Power and ribbon routes leave a service loop for opening the lid. The external
connector bodies must be firmly mounted; cable ties provide internal retention
but are not a certified cable gland or a substitute for a proper panel connector.

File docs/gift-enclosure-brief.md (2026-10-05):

# Inge — gift enclosure design brief

Status, 5 October 2026: the five digital enclosure kits are completed in
[`cad/enclosure-comparison`](../cad/enclosure-comparison/README.md), with an
offline viewer, per-design STL archives, assembly guides and fresh geometry
checks. The confirmed enclosed components are the panel, ESP32, acrylic and
wiring; the power adapter remains external. **Hardware fit remains unverified.**
The comparison family uses 1 mm acrylic and existing cable pass-throughs.
[`cad/inge-after-hours`](../cad/inge-after-hours/README.md) is the older single-case
prototype and the research notes below describe that earlier proposal. The user
confirmed replacing the picture frame with the complete printed case.

All five supplied photos have been inspected. The moulded panel marking reads
P2.5-1 / 80×160; the board has USB-C and four corner holes. The external adapter
label appears 5 V / 3 A / 15 W and needs physical confirmation. No ruler or hole
measurements were supplied. USB-C flange, power-inlet mount, PCB and rear-depth
parameters therefore remain provisional. The prototype uses a short data-capable
USB-C extension, a proposed extra component requiring selection before final fit.

Artilect is the recommended Toulouse venue for the 9 October birthday deadline,
based on posted public opening times and guided printing access. Its official
220×220 mm Ender 3 bed accommodates the prototype's 182.8×102.8 mm footprint.
CampusFab lists Bambu machines but its fresh homepage showed no forthcoming
opening session during research; neither venue has been booked or contacted.
See the CAD README for citations, print workflow and remaining measurements.

The original research notes below remain useful design context; where they differ,
the prototype README and measured parameters take precedence.

## Direction

A small architectural desk object, provisionally labelled **INGE / AFTER HOURS**:
a clean dark frame, recessed LED face, fine parallel ventilation ribs, and a
single optional coloured accent. Keep the inscription on a replaceable rear
nameplate so the front stays quiet. A separate shallow wedge stand provides a
comfortable viewing angle without complicating the main enclosure print.

This is a proposal, not an assumption about Inge's preferred colours or sensory
preferences. Confirm the visual direction before finishing decorative details.

## What the repository establishes

- One Waveshare 64×32 HUB75/FM6124 panel and a classic ESP32-WROOM development
  board. Neither the exact panel pitch nor the development-board PCB is known.
- The panel uses an external regulated 5 V supply. The README explicitly keeps
  the ESP32 external 5 V pin disconnected while it is powered from USB; grounds
  are shared. A USB-C socket on the actual development board is not confirmed.
- BOOT changes display mode; BOOT and EN/RST can also be needed for servicing.
- No physical dimension drawings, enclosure CAD, or component photographs were
  found among the repository's tracked/project files inspected for this brief.

64×32 is a pixel count, not a case size. Waveshare lists P2.5, P3, P4, and P5
variants with respective face dimensions 160×80, 192×96, 256×128, and 320×160 mm.
Its current specification lists 5 V / 2.5 A for P2.5/P3 and 5 V / 4 A for P4/P5.
Confirm the actual SKU; these are not measurements of this project's panel.

## Mechanical architecture

1. **Front frame and shell:** retain the panel using its actual mounting bosses
   or holes, with insulating spacers and no force against the LEDs or solder
   joints. Avoid covering the outermost pixels. Use a shallow protective rim;
   test any optional smoked acrylic separately for readability and reflections.
2. **Removable rear lid:** screw attachment for repeatable access. Reserve room
   for actual screw lengths and component clearances. Start with captive nuts;
   insert pockets can be substituted once the user's fastener stock is known.
3. **Removable controller carrier:** mount the real board, keeping its antenna
   away from the panel's metal backing and bundled conductors. Provide internal
   BOOT/EN access and, if needed, a non-preloaded external BOOT plunger.
4. **Replaceable rear connector plate:** exactly two functional cable openings,
   labelled `5 V POWER` and `USB / FLASH`. Size power opening for the selected
   inlet or strain-relieved captive cable. Prefer direct access to the actual
   board USB socket if it is USB-C and placement permits; otherwise reserve a
   mount for a verified USB data-capable panel extension, not a charging cable.
5. **Cable routing:** separate perimeter channels for the power pair and HUB75
   ribbon, tie-down slots, rounded exits, and service loops at removable parts.
   Keep the ribbon fold gentle; do not trap cables beneath the lid or over vents.
   Cable strain relief attaches to the shell, not the board connector.
6. **Passive cooling:** lower intake and upper rear exhaust slots, with stand
   clearance underneath. Keep slots away from fastening bosses and electrical
   connections. Check enclosed temperature under sustained real usage before
   calling the design complete.

Initial CAD starting values, to validate with fit coupons: 2.4 mm walls, 3 mm
lid, approximately 0.3 mm mating clearance per side, four M3 lid fasteners,
and a 10-degree removable wedge. These are design targets, not measured fit or
print specifications. Case depth follows the deepest connected component plus
its actual cable bend, mounting, and airflow clearance; do not assume 40 mm is
enough. Large variants may need a split shell to fit the printer bed.

## Power arrangement to resolve before construction

Default proposal: keep the mains adapter outside the gift enclosure; only
regulated low-voltage wiring enters it. The power inlet must be rated for the
confirmed panel plus controller load and use the confirmed polarity.

A two-port case does not establish a safe single-cable everyday power circuit.
If the power inlet is to feed both panel and ESP32, inspect the actual board's
power schematic and choose a supported supply-selection/isolation arrangement
before connecting computer USB at the same time. Preserve the README's existing
restriction until this is verified. Do not simply join external 5 V and USB VBUS.
Allow carrier space for any required distribution or isolation module only after
its actual dimensions and wiring have been specified.

## Editable CAD and print workflow

Use a parameterised OpenSCAD source with separate shell, lid, connector plate,
controller carrier, and stand modules. Inputs should include the measured panel
outline and mounting-hole coordinates, board outline and hole coordinates,
connector envelopes, cable clearance, printer bed, wall thickness, mating
clearance, and fastener dimensions. Use explicit unknowns rather than plausible
defaults for the component dimensions.

After measurements: produce the editable `.scad`, per-part STL files, an assembly
view, dimensions/fastener list, and a brief assembly guide. Validate manifold
exports, slicer size/orientation, interference and cable access. Print a mounting
corner and connector plate first; correct fits before printing the full shell.
PETG is a reasonable starting material for the functional enclosure; use the
printer/filament manufacturer's profile and test the finish. Material choice
alone does not validate the enclosure's thermal behaviour.

Final fit checks: LEDs unobstructed, panel securely retained, plugged-in cables
clear lid, no pinched wires, inlet strain relief holds, USB upload works with the
approved power procedure, BOOT remains usable, Wi-Fi stays reliable, and the
closed case stays within component/material limits during sustained operation.

## Measurements and choices still needed

- Exact panel SKU; front/back photos; width, height, rear depth; hole/boss
  positions relative to one corner; connector locations and plugged-in depth.
- Exact ESP32 board or clear top/bottom photos; PCB width/length, mounting holes,
  USB connector type/location, and maximum height with its wiring attached.
- Power adapter output rating, existing plug/connector and polarity, and whether
  the single power inlet should supply both panel and controller in daily use.
- Every other part to enclose, with dimensions: e.g. distribution board, audio
  board, speaker or another project. Their presence is **not** assumed.
- Printer model/build volume, material available, and fastener preference.
- Preferred look and stand/wall orientation; desired physical nameplate wording.

## Primary references

- [Waveshare panel family specifications](https://docs.waveshare.com/RGB-Matrix-Px-64x32)
- [Waveshare resources and official 2D drawing link](https://docs.waveshare.com/RGB-Matrix-Px-64x32/Resources-And-Documents)
  — follow the drawing matching the confirmed SKU; dimensions have not been
  transferred from a drawing into CAD yet.
- [OpenSCAD documentation](https://openscad.org/documentation)
- [OpenSCAD export and customisation manual](https://files.openscad.org/documentation/manual/OpenSCAD_User_Manual.html)
- [Prusa PETG material guidance](https://help.prusa3d.com/article/petg_2059?product=mmu3)

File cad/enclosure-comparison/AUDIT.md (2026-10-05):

# Enclosure audit — revision 3

The previous work contained all five STL sets and static previews but stopped
before producing the referenced print guide, audit, generated viewer or packaged
kits. Its geometry report passed, but some preview and source assembly states
differed and several practical fit questions were not documented.

## Corrections completed

| Finding | Result |
| --- | --- |
| `PRINT-GUIDE.md`, `AUDIT.md` and `viewer.html` were referenced but missing | Complete guides, this audit and the generated standalone viewer are included |
| No portable five-design handoff or per-design download | Each variant has a ZIP with shared CAD source, quantities, previews and guides; the full archive also contains the offline viewer |
| OpenSCAD assembly omitted cradle feet and PCB | Feet and nominal PCB now appear; Python uses the same placement |
| Exploded CAD, image and viewer used different offsets | Viewer offsets come from the checked assembly; CAD and Python exploded placement agree |
| Acrylic coupon grooves had a 0.3 mm roof | Grooves now open from above, with a 1.2 mm floor |
| Keeper used a nominal 2 mm bore as an M2 pilot | Default is now a 1.6 mm pilot, with 1.6/1.8 mm coupon holes; still test the printed fit |
| Board and spacer dimensions were hardcoded in previews | Editable source/build parameters populate the manifest, assembly, checks and viewer |
| Missing STL files could escape the mesh loop | Validation requires the exact expected part set and matching body dimensions |
| Stale source/exports could be packaged as passing | Export records source hash; validation records file hashes; packaging refuses modified checked inputs |
| Only front/rear/keeper head envelopes were checked | Panel, bridge and PCB screw-head envelopes and four PCB bolt passages are checked too |
| Viewer claimed diagnostic slicing without a report | Claim removed; provided diagnostic profile is labelled unverified |

## Digital validation performed

All five kits were regenerated using official OpenSCAD 2026.10.03 Node WASM.
For 65 distinct STL files, validation checks one connected solid, watertightness,
consistent winding, positive volume, Z=0 base and assumed bed/brim clearance.
Assembly checks intersect actual transformed meshes pairwise, including nominal
panel/PCB/acrylic and the documented screw-head envelopes. They also check a
panel connector reserve, USB plug reserve, PCB wiring reserve and four clear
PCB bolt paths. `validation.json` contains the result and its checked file hashes.

The viewer has five design tabs, front/rear views, open-back and exploded modes,
mouse/keyboard rotation and zoom. It embeds actual STL geometry and uses the
same exploded transforms as the validation/render assembly. These visual modes
are review views; they are not STL files intended to be printed as one object.

## Physical measurements and tests still needed

| Item | Evidence/default | Required real check |
| --- | --- | --- |
| Panel | P2.5/80×160 marking in project photos; saved official drawing evidence | Actual outline, connected depth and insert engagement |
| Panel mounting | Outer four drawing M3 centres, 125 × 65 mm | Confirm these inserts on the physical panel revision |
| ESP32 | Photographed USB-C board with corner holes; 58 × 29 / 52 × 23 mm defaults | Board dimensions, hole diameter/spacing, components and underside jumpers |
| Acrylic | Current comparison CAD records owner-confirmed 1 mm thickness | Test actual sheet/pad in the printed recess; older prototype used 2 mm |
| Nut and screw fit | 6.1 × 2.5 mm carrier channels, documented nominal heads | Actual nuts, washers, head heights and printed pilot engagement |
| Wiring | Fixed 20 mm panel connector reserve and 64 × 36 × 38 mm PCB reserve | Plugged cables, slack, connector positions and actual bend requirements |
| Cable cassette | R25 mm oval guide; 6 mm effective bundle estimate | Bundle diameter, usable slack and strap retention without crushing wires |
| Feet | Two printed cradles, pads/tape proposed | Cable-loaded stability and attachment |
| Printing | 220 × 220 × 250 mm assumed bed; 5 mm brim allowance | Workshop machine, slicing/supports, tolerance and finished part quality |
| Electronics in closed case | Existing project power procedure retained | USB upload, Wi-Fi, BOOT/EN service access and sustained temperature |

No thermal certification, electrical redesign, actual print/slice result or
physical fit certification is implied by a passing mesh report. Additional
speaker/power-distribution components are outside the confirmed component list.

## Source evidence

- [Waveshare panel documentation](https://docs.waveshare.com/RGB-Matrix-Px-64x32).
- [Waveshare P2.5 drawing](https://files.waveshare.com/wiki/RGB-Matrix-P2.5-64x32/RGB-Matrix-P2.5-64x32-2D.dwg);
  the existing extraction is preserved in `evidence/matrix-mounting-evidence.json`
  and its diagram. These recorded coordinates are not a new hardware measurement.
- [OpenSCAD official downloads](https://openscad.org/downloads.html), including
  the Node WASM build used to regenerate the models.
- Project `pictures/` and `docs/gift-enclosure-brief.md` provide the original
  hardware context. The original brief and single-case README remain history;
  this folder describes the five-design revision.

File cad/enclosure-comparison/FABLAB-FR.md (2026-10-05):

# Fiche atelier — cinq boîtiers INGE / AFTER HOURS

Dossier numérique complet, révision 3 du 5 octobre 2026. **Ajustement matériel
non vérifié.** Apporter le panneau, l'ESP32, les câbles branchés et l'acrylique.
Composants confirmés : panneau LED, ESP32, plaque acrylique et câblage uniquement.
L'alimentation secteur reste à l'extérieur.

## Choisir une seule variante

| Variante | Largeur × hauteur × profondeur, mm | Acrylique 1 mm | Bac à câbles |
| --- | --- | --- | --- |
| Line | 190 × 110 × 94,5 | Découper à 164 × 84 | 14 mm |
| Orbit | 202 × 122 × 96,5 | Découper à 164 × 84 | 20 mm |
| Gallery | 206 × 156 × 96,5 | Feuille entière 180 × 130 | 20 mm |
| Vault | 206 × 156 × 122,5 | Feuille entière 180 × 130 | 40 mm |
| Console | 202 × 122 × 108,5 | Découper à 164 × 84 | 30 mm |

Vault offre le plus de place pour les fils ; Line occupe le moins de place.
La profondeur inclut la plaque arrière, mais pas les têtes de vis ni les lèvres
des pieds. Les pieds ajoutent 4 mm sous le boîtier. Ouvrir `viewer.html` pour
comparer et voir le démontage ; `comparison.png` fonctionne sans WebGL.

## Avant d'imprimer le grand boîtier

- Vérifier le panneau : 160 × 80 × 14,5 mm nominaux ; quatre inserts M3 arrière
  extérieurs espacés de 125 × 65 mm. Mesurer la profondeur utile des inserts pour
  choisir les vis sans toucher l'électronique. Le dessin fourni est une référence.
- Mesurer le PCB ESP32 et ses trous. Valeurs provisoires : 58 × 29 mm, trous
  52 × 23 mm. Support réglable : entraxe longitudinal 30–64 mm, transversal
  0–32 mm. Ne pas agrandir les trous du PCB pour utiliser des vis M3.
- Tester `coupon.stl`, `carrier.stl`, un `rail.stl`, un `spacer.stl` et `ports.stl`.
  Les rainures acryliques sont ouvertes sur le dessus : 1,0 / 1,2 / 1,4 mm.
  Les petits trous, de gauche à droite : 1,6 / 1,8 / 2,0 / 2,2 / 2,4 / 2,6 /
  2,8 / 3,0 / 3,4 mm. Les grands trous : 12,2 / 12,4 / 12,6 mm.
- Vérifier les passages de câbles : 22 × 14 mm pour l'alimentation, 32 × 18 mm
  pour l'USB. Les connecteurs existants passent dans les ouvertures ; aucune
  rallonge USB supplémentaire n'est imposée. Retenir les câbles par des sangles.
- Contrôler les câbles branchés, les courbures et l'accès BOOT/EN avec couvercle
  retiré. Réserve modélisée : 20 mm derrière le panneau, entre les traverses.

## Quantités par boîtier

Une pièce de chaque : `bezel`, `keeper`, `body`, `lid`, `carrier`, `cassette`,
`ports`. Deux `bridge`, deux `rail`, quatre `spacer`, deux `feet`.
Soit **17 pièces installées**, plus un `coupon` d'essai.
`ports_usb_c` remplace `ports` seulement après sélection et mesure d'un adaptateur
USB de panneau rond ; ne pas imprimer les deux pour le montage standard.

Pour un PCB acceptant des M3 : 30 vis/boulons M3, 14 écrous M3 et 4 vis M2.
Choisir les longueurs en fonction des empilements réels. Le support PCB traverse
le PCB + une entretoise de 20 mm + un rail de 3 mm + rondelle/écrou. Les vis du
panneau traversent une traverse de 3 mm puis ses inserts. Ne jamais atteindre les
composants. Tester/préparer les avant-trous imprimés de 2,6 mm (M3) et 1,6 mm (M2).
Les logements d'écrous du support mesurent 6,1 × 2,5 mm : vérifier les écrous.
Prévoir rondelles, sangles souples, patins et adhésif démontable pour les pieds.

## Impression et montage

STL en millimètres, à importer sans changement d'échelle. Le SVG de découpe
ajoute 1 mm de marge autour du tracé : page 166 × 86 ou 182 × 132 mm. Importer
à 100 % et découper le tracé ; ne pas redimensionner la page à la taille de plaque.
Une pièce par fichier ;
dupliquer les pièces selon les quantités. Tous les fichiers sont posés à Z=0.
L'encombrement maximal est 206 × 156 mm et tient sur un plateau supposé
220 × 220 mm, marge de 5 mm pour bordure comprise. Employer le profil validé de
l'atelier ; inspecter les ponts, évents et logements d'écrous dans le trancheur.
Aucun G-code machine n'est fourni et aucun essai d'impression n'est revendiqué.

1. Mettre l'acrylique dans la façade démontable, puis visser la bague `keeper`.
2. Visser façade et corps ; fixer le panneau par ses inserts arrière aux deux
   traverses, puis les traverses aux sièges du corps. Aucun appui sur les LED.
3. Sur l'intérieur du couvercle : fixer support et bac ; ajuster les rails et
   monter le PCB sur quatre entretoises. Composants orientés vers le couvercle,
   connexions sous le PCB vers le panneau. Consulter la vue éclatée.
4. Fixer la plaque de câbles à l'extérieur du couvercle. Attacher les fils,
   conserver une boucle pour ouvrir et éloigner les faisceaux de l'antenne.
   Boucler doucement le surplus dans le bac ; ne pas serrer la nappe HUB75.
5. Fermer avec quatre vis ; poser les deux pieds avec patins et adhésif démontable.
6. Tester stabilité avec câbles, retenue, affichage, USB, Wi-Fi et température
   en usage prolongé. Garder l'entrée externe 5 V de l'ESP32 débranchée lorsqu'il
   est alimenté par l'USB de l'ordinateur, conformément au projet.

Le guide anglais `PRINT-GUIDE.md` détaille les quantités par assemblage. Après
une modification des paramètres, régénérer les STL et `validation.json` avant
l'impression. L'ancien dossier `inge-after-hours` n'est pas cette famille de cinq.

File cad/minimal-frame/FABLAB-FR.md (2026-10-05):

# Fiche atelier — cadre minimal, arrière fermé

**Deux pièces imprimées installées : un cadre et une coque arrière ventilée.**
Le panneau est maintenu par ses inserts arrière ; l'ESP32 est immobilisé dans
des glissières intégrées. Sa prise USB-C et le connecteur d'alimentation existant
sortent directement sur la face arrière. Le bloc secteur reste à l'extérieur.

Les contrôles numériques passent. **Ajustement physique non vérifié** : mesurer
l'ESP32, le connecteur DC et les fiches avant de lancer la grande coque.

Vues du cadre et de l'arrière

## À fabriquer

| Fichier | Quantité | Dimensions, mm | Face sur le plateau |
| --- | --- | --- | --- |
| `stl/frame.stl` | 1 | 176 × 96 × 23,3 | Arrière du cadre, avec les quatre oreilles |
| `stl/rear.stl` | 1 | 176 × 96 × 84,7 | Face arrière extérieure, avec les prises |
| `acrylic-outline.svg` | 1 plaque | 164 × 84 × 1 | Découpe, coins de rayon 1 mm |

Boîtier assemblé : **176 × 96 × 108 mm**, hors têtes de vis et fiches branchées.
L'ESP32 est placé sur chant pour orienter sa prise USB-C vers l'arrière. Sa
longueur explique la profondeur ; aucun câble USB de rallonge n'est nécessaire.
L'acrylique fourni de 180 × 130 × 1 mm doit être recoupé. Importer le SVG à 100 % :
la page mesure 166 × 86 mm, le contour à découper 164 × 84 mm.

Les STL sont déjà orientés sur Z=0. Ne pas les redimensionner. Chaque pièce tient
sur un plateau de 220 × 220 mm, bordure de 5 mm comprise. Elles tiennent également
ensemble : cadre et coque espacés de 10 mm, enveloppe de 186 × 212 mm avec bordure.
Sur deux imprimantes, affecter le cadre à l'une et la coque à l'autre ; le temps
écoulé dépend alors de la pièce la plus longue.

Utiliser le profil matière/machine validé de l'atelier. Point de départ à trancher :
buse de 0,4 mm, couches de 0,20 à 0,28 mm ; conserver les parois de 1,6 mm de la
coque et le fond de 1,8 mm. Le modèle privilégie les parois verticales et les
petits ponts de 3 à 3,4 mm. Inspecter les évents, rainures et fenêtres de colliers
dans le trancheur. La façade possède un épaulement en pente pour l'orientation
indiquée. Impression sans supports visée, à confirmer dans le trancheur.

Volume géométrique plein : 165,5 cm³, soit environ 205 g à 1,24 g/cm³. Ce n'est
ni la consommation du trancheur ni un temps garanti. La contrainte de six heures
est abandonnée ; on vise une fabrication relativement rapide avec peu de pièces.

## Vérifier l'ajustement

- Panneau nominal : **160 × 80 × 14,5 mm**, inserts M3 extérieurs à entraxe
  **125 × 65 mm**. Jeu du logement : **0,35 mm par côté**.
- Essayer `fit-tests/fit_corner.stl` sur un coin du panneau. L'essai ne vérifie
  pas tout l'entraxe des inserts. Le PCB se teste avec `board_gauge.stl`.
- PCB provisoire : **58 × 29 × 1,6 mm** ; rainures de **2,2 mm**, engagement
  de **0,8 mm** sur chaque bord long. Ces bords doivent être libres de composants.
  La face composants est tournée vers la paroi latérale, avec une réserve
  modélisée de 25 mm pour les connecteurs/fils.
- Vérifier l'emplacement réel de l'USB-C : ouverture arrière **12 × 20 mm**,
  fiche testée numériquement dans une enveloppe de **10 × 14 mm**. Le PCB est
  arrêté à 2,8 mm de la face extérieure ; le nez USB supposé dépasse de 1,5 mm.
- Adaptateur DC provisoire : corps **35 × 16 × 14 mm**, nez supposé Ø11 mm,
  passage Ø13 mm. Mesurer le corps, la position de la prise, l'épaulement et
  l'accès aux borniers. Le berceau retient l'adaptateur au moyen de deux colliers.
- Réserve numérique derrière le panneau : **20 mm** sur une zone de 148 × 48 mm.
  Vérifier la place avec les fils réellement branchés et leurs courbures.

Les essais sont facultatifs dans le kit et ne restent pas dans l'assemblage.
Les dimensions se modifient en tête de `model.scad` ; reconstruire les STL et
relancer `validate.py` après modification. Les fichiers `reference/` représentent
le matériel pour les contrôles : **ne pas les imprimer**.

## Quincaillerie et montage

- 4 vis **M3 × 30 mm** pour fermer le boîtier : environ 6,7 mm d'engagement dans
  les avant-trous de 2,6 mm, profonds de 11 mm. Préparer/tester le vissage sans forcer.
- 4 vis M3 courtes pour le panneau : elles traversent **3 mm** de plastique,
  puis les inserts du panneau. Mesurer la profondeur utile des inserts pour
  choisir la longueur ; elle n'est pas connue.
- 3 colliers fins, largeur **2,5 mm** : un pour le PCB, deux pour le DC ; prévoir
  une longueur suffisante (100 mm convient aux enveloppes modélisées).
- Petites bandes d'adhésif démontable pour l'acrylique ; patins adhésifs si souhaité.

1. Introduire le panneau **par l'avant du cadre**, puis visser ses quatre inserts
   depuis l'arrière à travers les oreilles. Il ne doit pas être forcé dans le cadre.
2. Poser l'acrylique par l'avant dans sa feuillure, avec de petites bandes
   d'adhésif démontable sur la portée d'environ 1,65 mm. Ne pas coller les LED.
3. Coque ouverte, glisser le PCB **extrémité USB en premier** dans les deux
   rainures. Le connecteur doit arriver dans la fenêtre arrière. Passer un collier
   par les deux fenêtres fermées situées juste au-dessus de l'autre extrémité du
   PCB ; il empêche le PCB de ressortir. Placer la tête du collier hors des composants.
4. Poser le connecteur DC contre l'ouverture ronde. Faire passer deux colliers
   autour du corps et à travers les fenêtres opposées du berceau. Les serrer
   suffisamment pour empêcher le connecteur de bouger lors du branchement.
5. Brancher le câblage en gardant une boucle pour rouvrir. Contrôler le passage
   des fiches USB/DC et la retenue du matériel, puis joindre cadre et coque.
6. Fermer avec les quatre M3 × 30 depuis les coins de la face avant. Pour ouvrir,
   enlever ces quatre vis ; le PCB et le DC restent fixés à la coque arrière.
7. Tester affichage, USB, Wi-Fi et température en usage prolongé. Conserver la
   règle du projet : débrancher l'entrée externe 5 V de l'ESP32 lorsqu'il est
   alimenté par l'USB de l'ordinateur.

Fixations internes et profondeur

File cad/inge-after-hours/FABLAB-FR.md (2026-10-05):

# Fiche atelier — cadeau « INGE / AFTER HOURS »

**Objectif :** boîtier complet pour un écran LED, à offrir le 9 octobre 2026.
Remplace le cadre photo. Source paramétrique OpenSCAD et STL de prototype fournis.
**Ne pas lancer la coque complète avant le contrôle des pièces réelles.**

## Aspect souhaité

Coque anthracite, finition régulière, vis arrière discrètes, petite platine de
connecteurs contrastée. Gravure arrière « INGE / AFTER HOURS ». Choisir un PETG
et un profil déjà maîtrisés par l'atelier ; l'aspect final dépend du filament,
du réglage et de l'orientation, pas seulement du modèle d'imprimante.

## Encombrement et pièces

Coque : 182,8 × 102,8 × 60 mm. Ensemble avec couvercle et platine : profondeur
maximale 66 mm. Toutes les pièces tiennent séparément sur un plateau 220 × 220 mm,
avec environ 5 mm de bordure autour de la coque.

- 1 coque `shell.stl`, face avant contre le plateau.
- 1 couvercle `lid.stl`, face plate contre le plateau.
- 1 platine `ports.stl`, gravures POWER / USB vers le haut.
- 1 support ESP32 `carrier.stl`, base contre le plateau.
- 4 clips `clip.stl` et 2 pieds `stand.stl`.
- 1 éprouvette `coupon.stl` à imprimer en premier.

STL en millimètres, géométries fermées vérifiées. Pas de G-code : trancher avec
le profil de l'imprimante réellement utilisée. Point de départ : buse 0,4 mm,
4 parois, remplissage 15–20 %, couches 0,2 mm pour les essais, éventuellement
0,16 mm pour les pièces visibles. Contrôler les ponts et surplombs des passages
pour colliers et des bossages arrière ; supports locaux si le trancheur l'exige.

## Vérification sur place avec le matériel

Le panneau est un Waveshare P2.5 64×32, nominalement 160 × 80 mm. Vérifier la
profondeur arrière, le dégagement des connecteurs branchés et la portée des clips
sur le cadre plastique, sans appui sur les soudures. Confirmer que la lèvre avant
ne masque aucune LED.

Carte identifiée par son propriétaire : **ESP32 NodeMCU WiFi Bluetooth Module
ESP32 WROOM 32 Development Board**, version USB-C photographiée. Ce nom ne
précise pas la révision mécanique. Mesurer le circuit ESP32 USB-C, ses quatre trous et son épaisseur avec les fils.
Le motif de perçage du support est **provisoire** (modifiable dans `enclosure.scad`).
Le support est démontable ; la position de l'antenne et les fils doivent rester
éloignés autant que possible du dos du panneau.

Sélectionner une courte rallonge **USB-C avec données** à fixation panneau et une
embase d'alimentation 5 V correspondant au bloc secteur. Vérifier les plans de ces
connecteurs avant de modifier la platine et l'éprouvette : le trou de 8 mm est un
alésage de fixation provisoire, pas une affirmation du diamètre du connecteur
actuel. Les deux ouvertures servent à POWER et USB / FLASH.

Tester une éprouvette, un support et un clip avant les grandes pièces. Ajuster les
jeux si nécessaire. Les avant-trous de 2,6 mm sont à valider puis tarauder pour M3 ;
choisir les longueurs de vis réelles sans atteindre le panneau ni les composants.
BOOT et EN restent accessibles couvercle retiré. Le prototype n'a pas de bouton
extérieur ; un poussoir nécessiterait la position mesurée du bouton.

## Montage et contrôles

Fixer le panneau, puis le support au couvercle. Attacher séparément les fils de
puissance et le ruban HUB75 aux guides périphériques. Garder une boucle de service
pour ouvrir le couvercle et fixer la retenue des câbles au boîtier. Ne pas obstruer
les évents. Ajouter des patins antidérapants aux deux pieds.

Le bloc secteur secteur reste **à l'extérieur**. Vérifier le circuit d'alimentation
avant de brancher simultanément l'entrée 5 V et l'USB d'un ordinateur : la carte
actuelle n'a pas de protection de sélection d'alimentation confirmée.

Avant emballage : contrôle USB/flash selon la procédure électrique validée,
connexion Wi-Fi, stabilité avec câbles branchés, températures en fonctionnement
prolongé, absence de fils pincés, et ouverture facile pour maintenance.

## Atelier conseillé

Artilect : https://www.artilect.fr/impression-3d — parc annoncé compatible avec
le gabarit, PETG et parcours d'initiation/réservation. Demander un accompagnement
pour la finition d'un cadeau et vérifier un créneau avant le 9 octobre. Aucune
réservation, prise de contact ou commande n'a été faite par l'assistant.

## Façade plexiglas fournie par le propriétaire

QWORK, lot de 10 plaques transparentes **130 × 180 mm**. Découper une fenêtre
**164 × 84 mm**, rayon des coins 1 mm, suivant `acrylic-front-164x84.svg` (échelle
1:1 en mm). Confirmer la matière sur l'emballage et choisir le procédé de coupe
adapté. L'épaisseur n'est pas précisée dans le titre produit : **la mesurer avant
l'impression de la coque** et régler `acrylic_thickness` (hypothèse actuelle : 2 mm).

Imprimer aussi `front_spacer.stl`, à plat. Montage : rebord avant, plexiglas,
entretoise périphérique, panneau LED, puis clips. Le jeu latéral est de 0,3 mm
par côté ; une fine garniture souple en périphérie absorbe le jeu en épaisseur.
Vérifier qu'aucune LED ne touche la plaque et qu'aucun clip ne la contraint trop.
La façade reste démontable par l'arrière, sans collage définitif.

Le canal inférieur guide les fils d'alimentation ; les attaches supérieures
maintiennent le ruban HUB75. Garder des courbes douces, une boucle pour ouvrir
le couvercle et les évents libres.

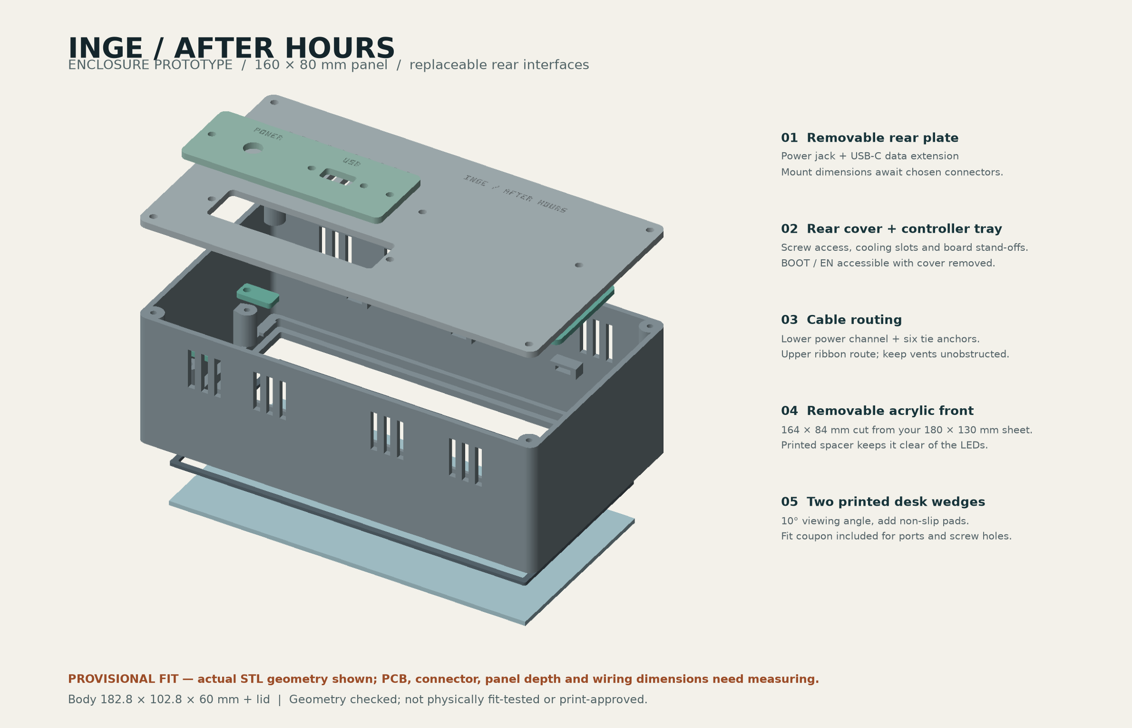
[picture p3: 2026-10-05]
cad/inge-after-hours/prototype-overview.png

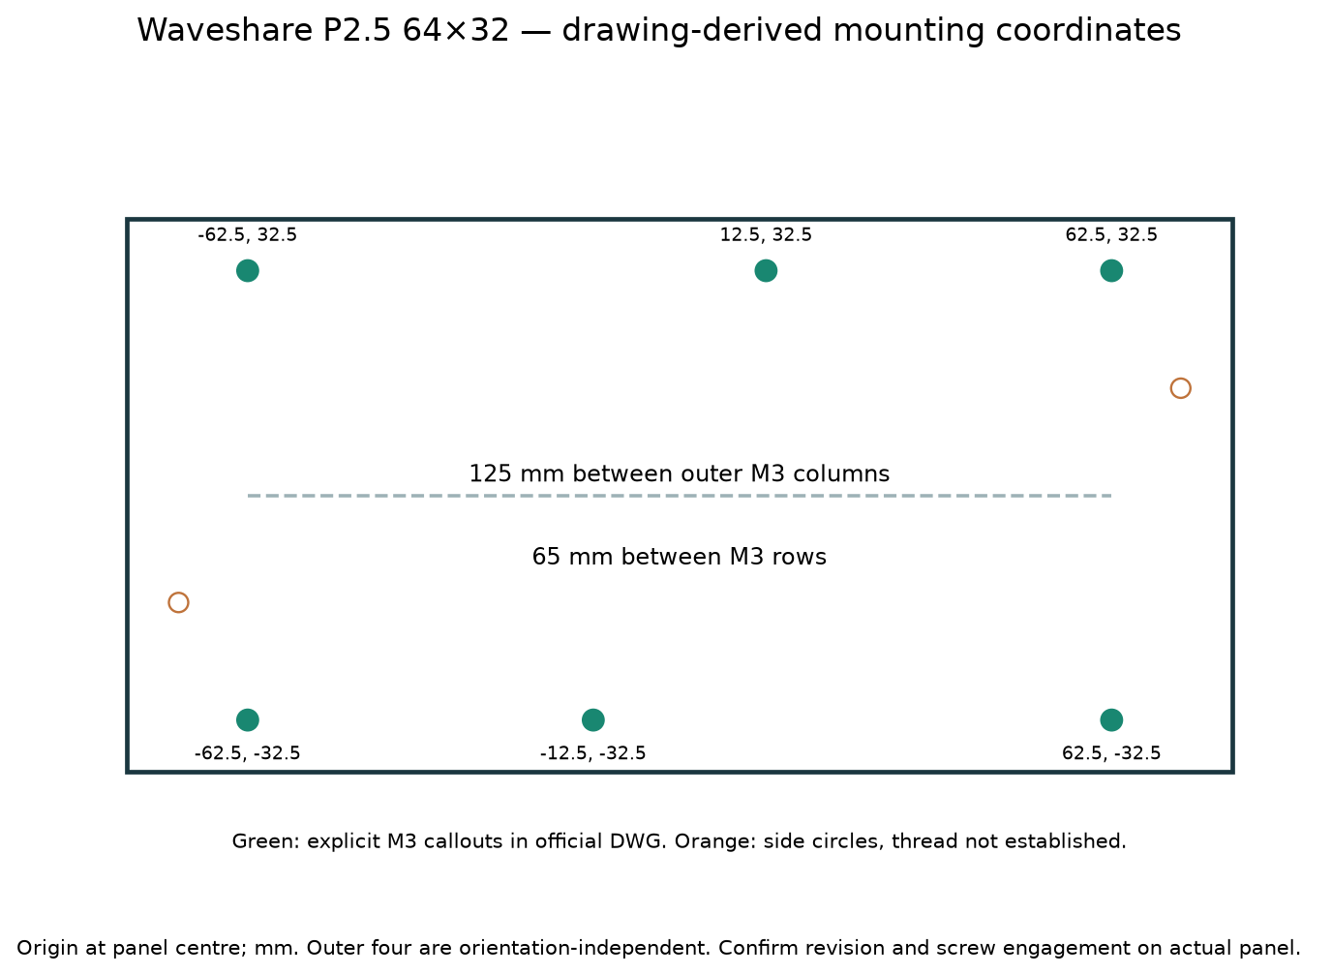
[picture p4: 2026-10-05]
cad/enclosure-comparison/evidence/matrix-mounting-evidence.png

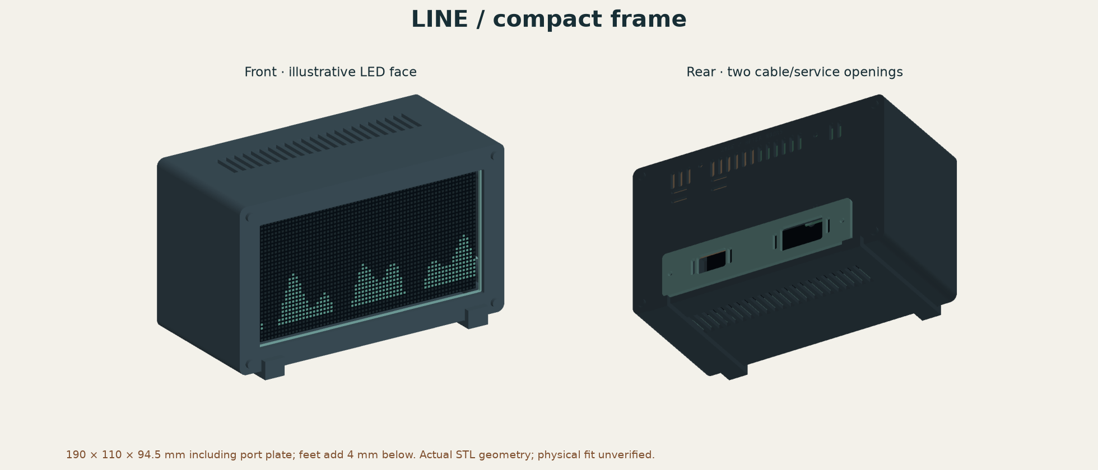
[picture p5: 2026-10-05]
cad/enclosure-comparison/01-line/preview.png

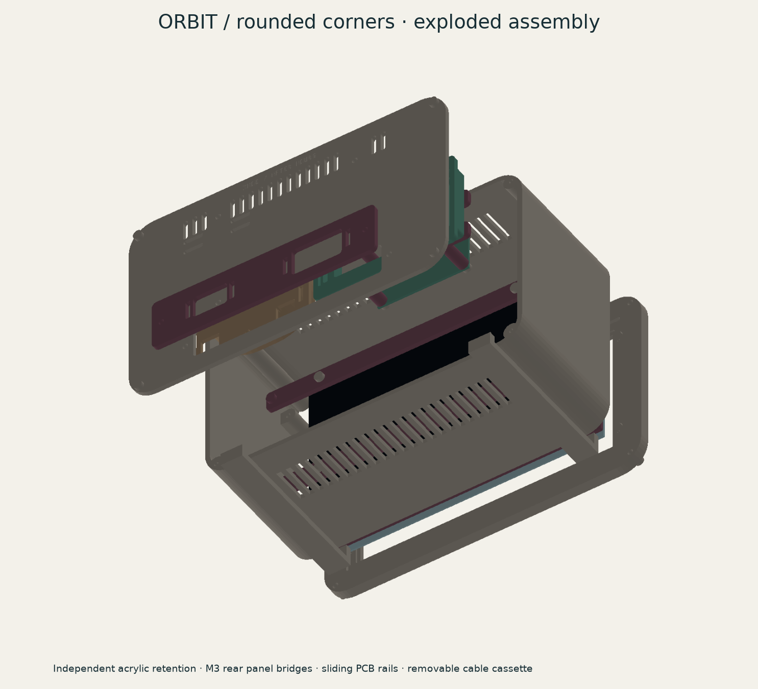
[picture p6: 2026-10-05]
cad/enclosure-comparison/02-orbit/exploded.png

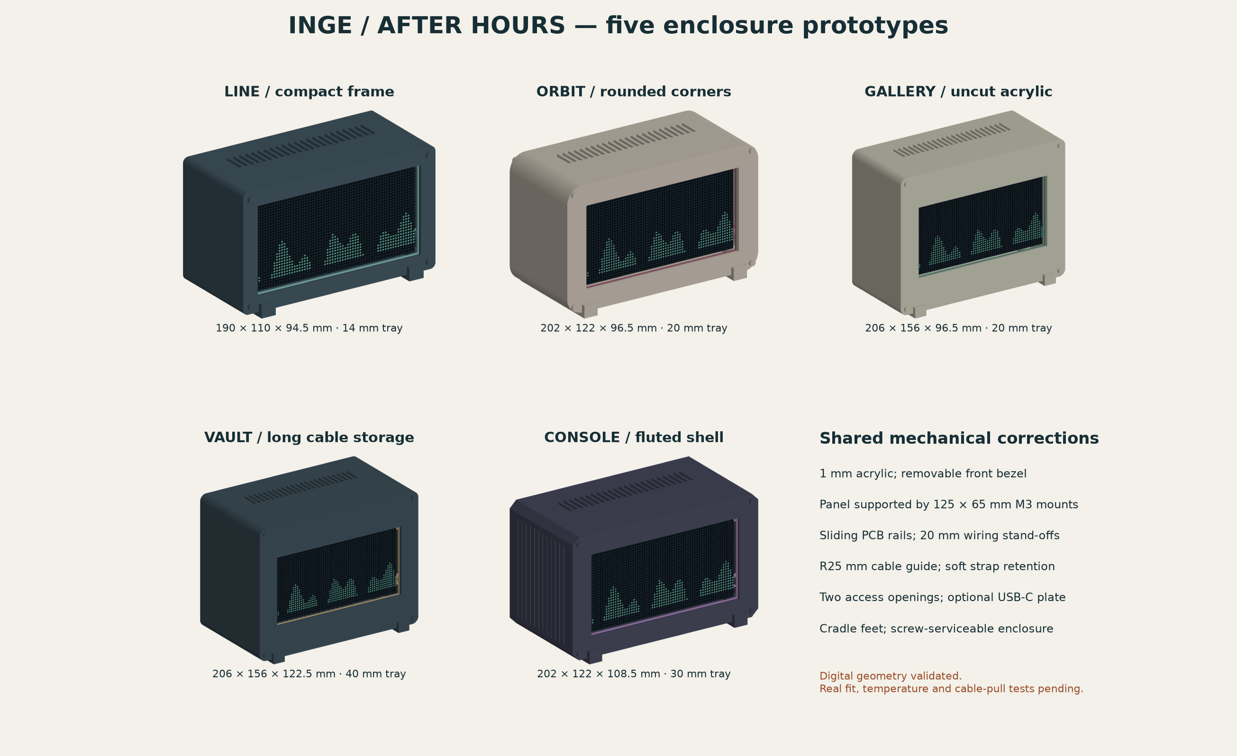
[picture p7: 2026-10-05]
cad/enclosure-comparison/comparison.png

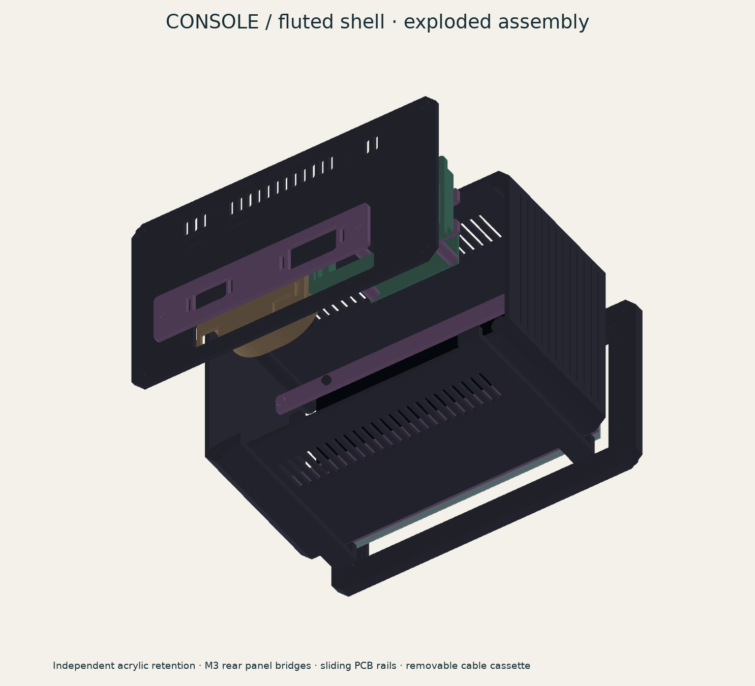
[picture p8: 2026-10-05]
cad/enclosure-comparison/05-console/exploded.png

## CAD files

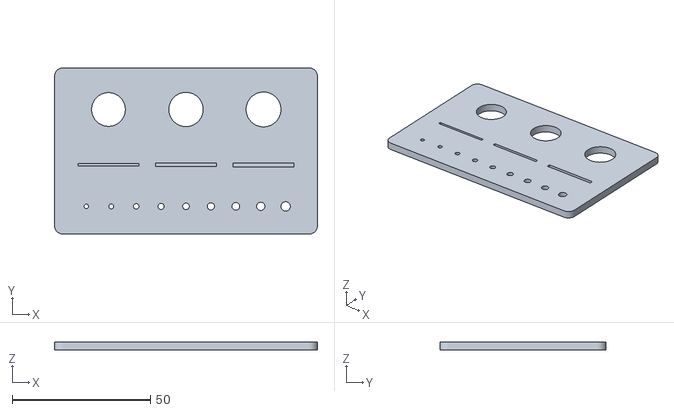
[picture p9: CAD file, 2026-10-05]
cad/enclosure-comparison/01-line/stl/coupon.stl
95.0 x 60.0 x 3.00

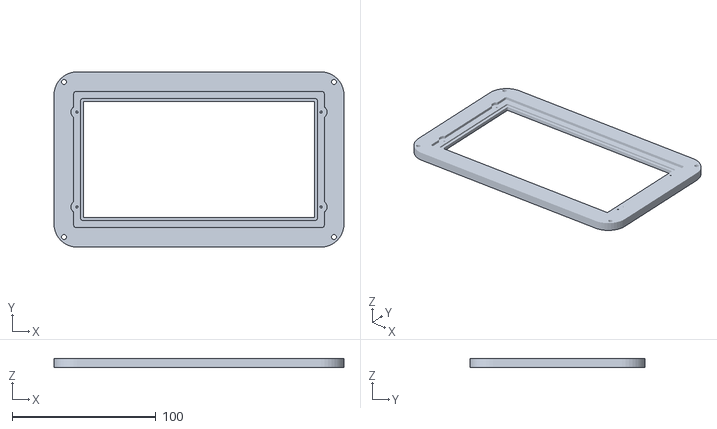
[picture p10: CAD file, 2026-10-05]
cad/enclosure-comparison/02-orbit/stl/bezel.stl
202.0 x 122.0 x 6.50

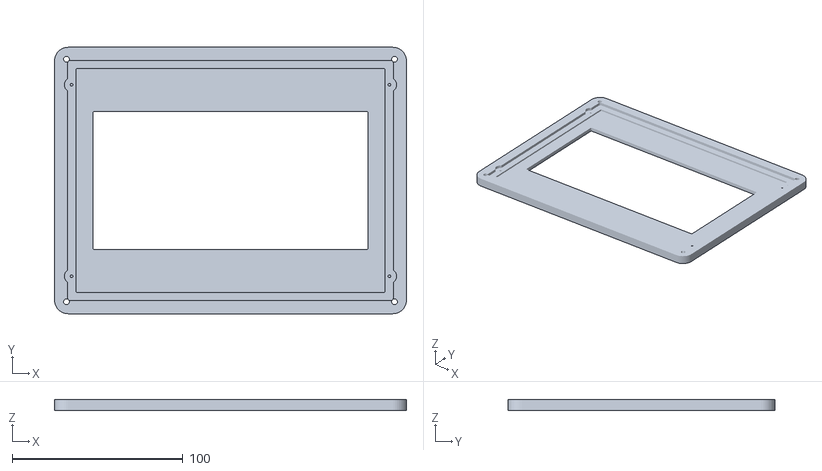
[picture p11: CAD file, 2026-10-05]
cad/enclosure-comparison/03-gallery/stl/bezel.stl
206.0 x 156.0 x 6.50

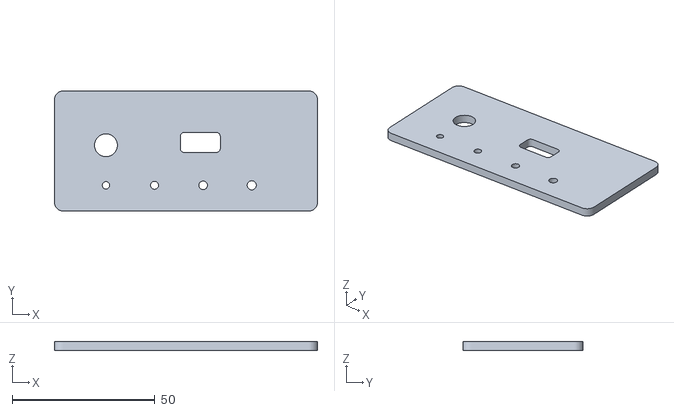
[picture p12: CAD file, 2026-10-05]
cad/inge-after-hours/prototype-stl/coupon.stl
92.0 x 42.0 x 3.00

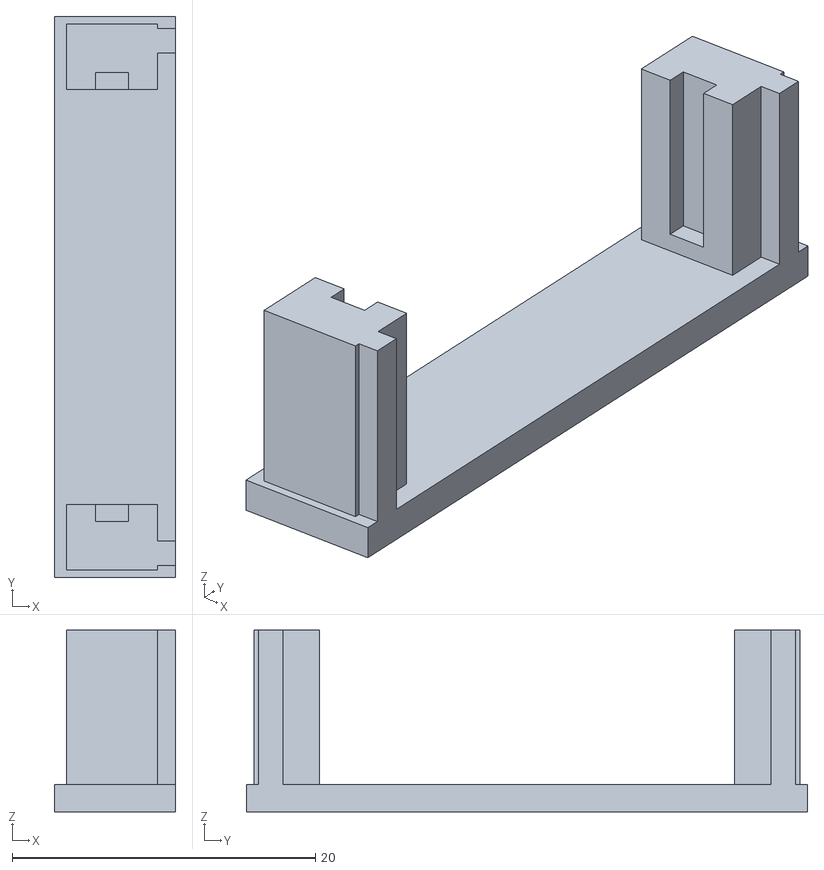
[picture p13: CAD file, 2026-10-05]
cad/minimal-frame/fit-tests/board_gauge.stl
8.00 x 37.0 x 12.0

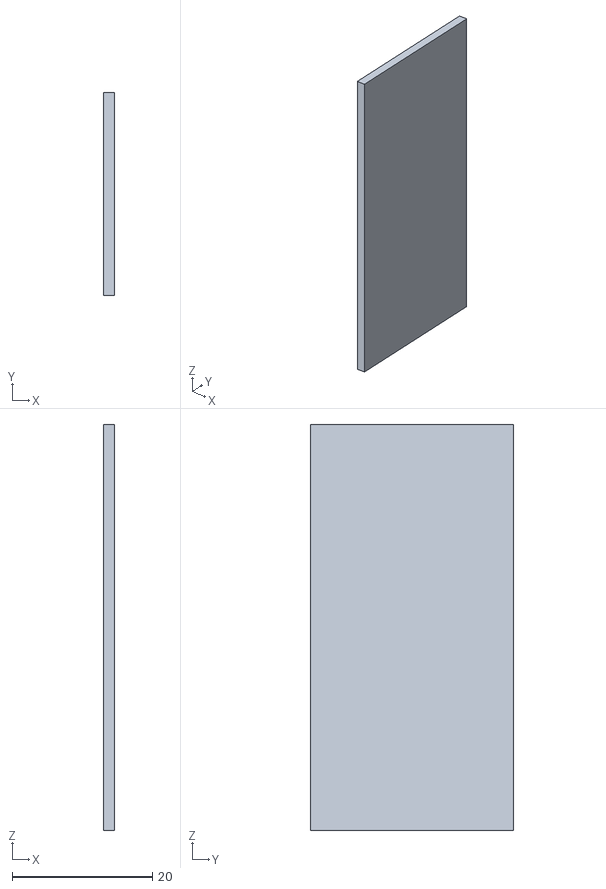
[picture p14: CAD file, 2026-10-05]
cad/minimal-frame/reference/pcb_mock.stl
1.60 x 29.0 x 58.0

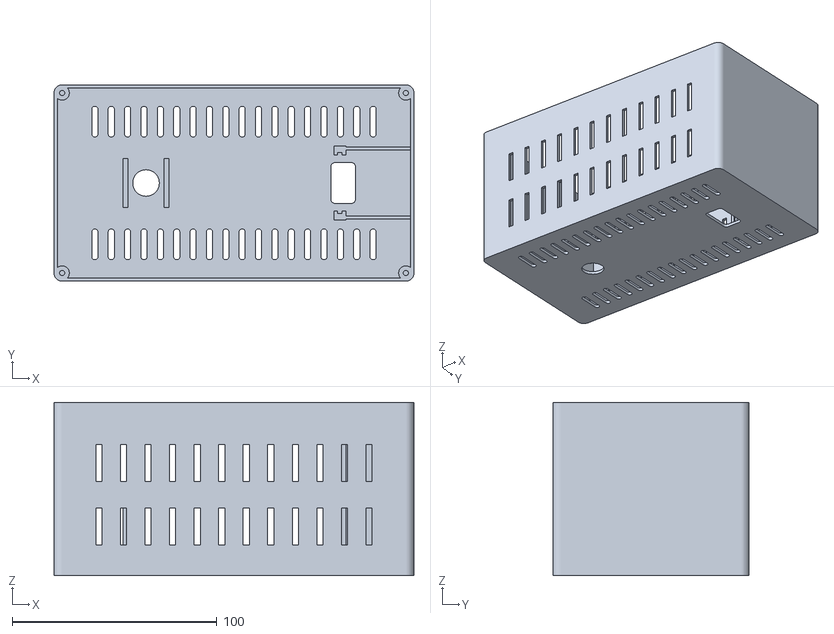
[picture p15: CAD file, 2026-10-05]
cad/minimal-frame/stl/rear.stl
176.0 x 96.0 x 84.7

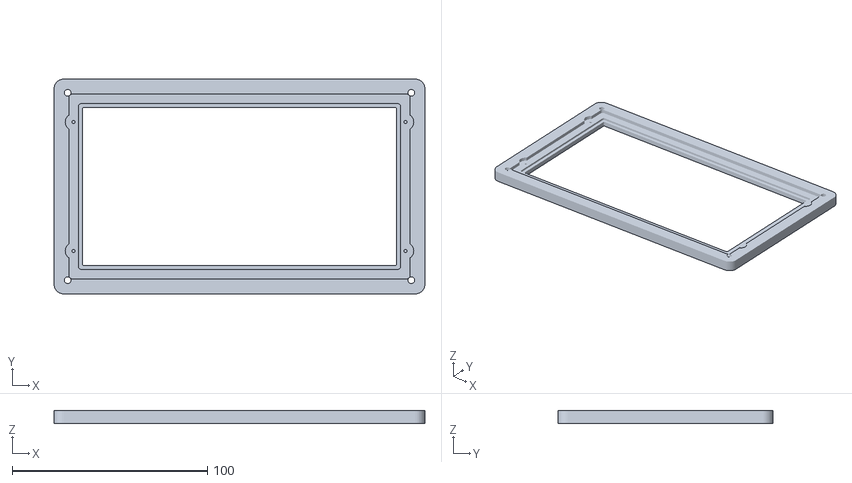
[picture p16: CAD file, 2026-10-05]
cad/enclosure-comparison/01-line/stl/bezel.stl
190.0 x 110.0 x 6.50

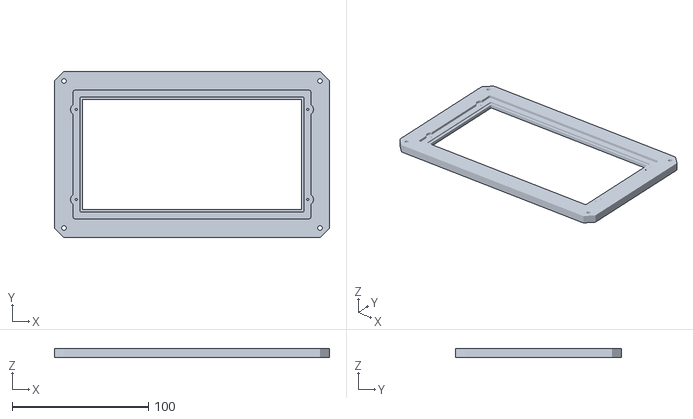
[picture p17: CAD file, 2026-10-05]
cad/enclosure-comparison/05-console/stl/bezel.stl
202.0 x 122.0 x 6.50

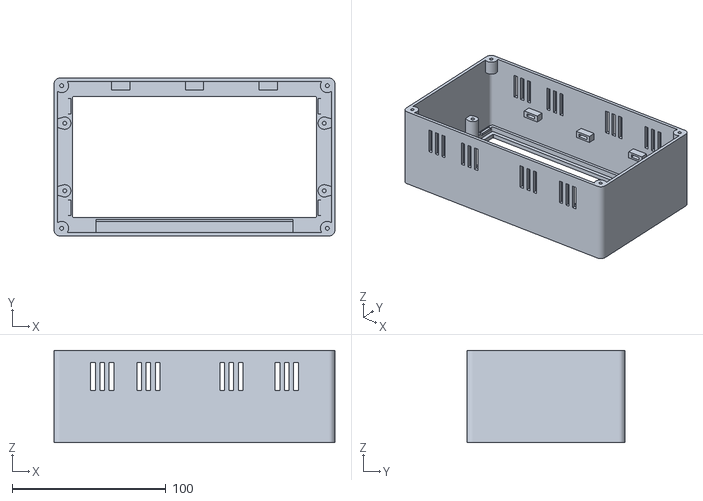
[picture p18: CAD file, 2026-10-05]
cad/inge-after-hours/prototype-stl/shell.stl
182.8 x 102.8 x 60.0

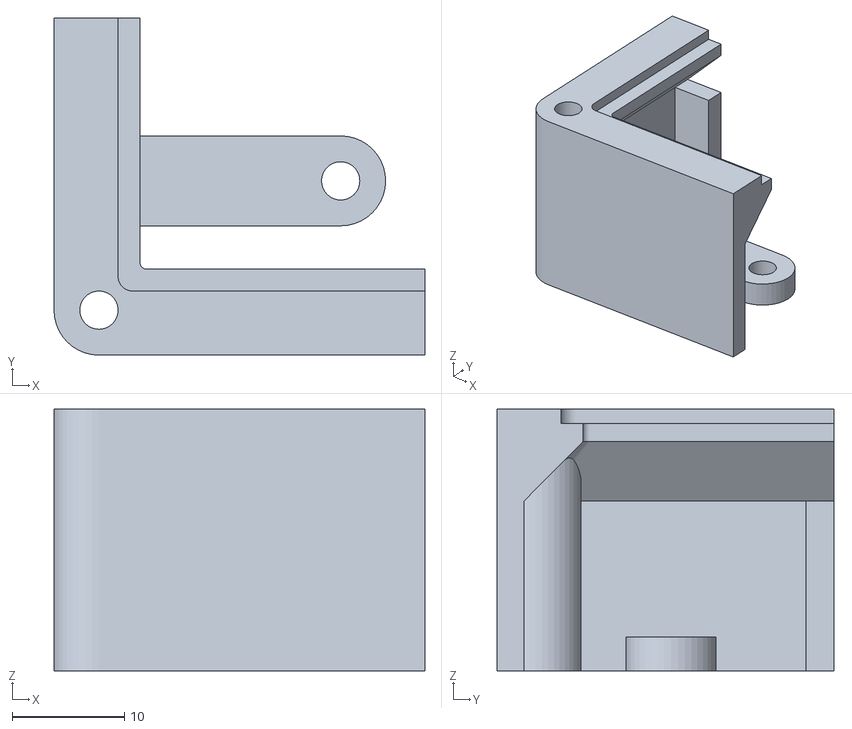
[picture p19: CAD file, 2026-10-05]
cad/minimal-frame/fit-tests/fit_corner.stl
33.0 x 30.0 x 23.3

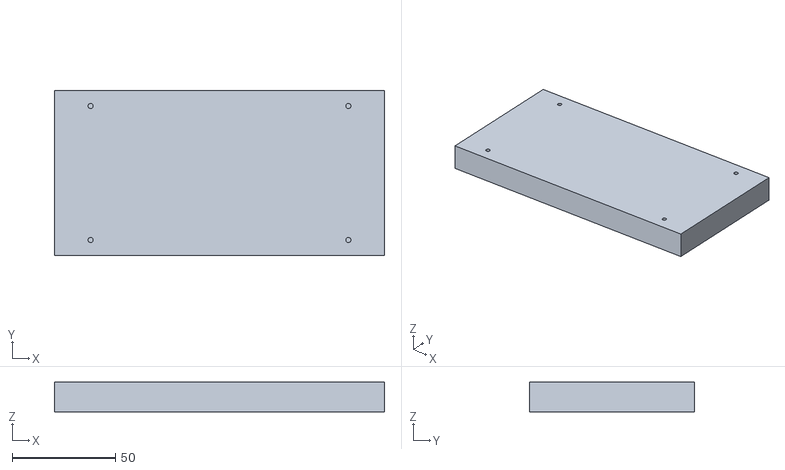
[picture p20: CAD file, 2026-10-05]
cad/minimal-frame/reference/panel_mock.stl
160.0 x 80.0 x 14.5

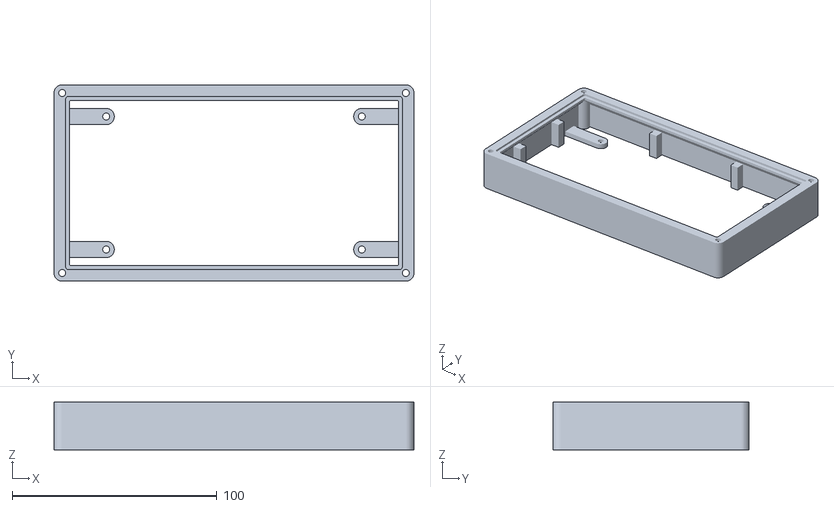
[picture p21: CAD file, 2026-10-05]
cad/minimal-frame/stl/frame.stl
176.0 x 96.0 x 23.3

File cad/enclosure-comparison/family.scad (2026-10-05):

/* INGE / AFTER HOURS, revision 3. All dimensions in mm.
   Five printable comparison prototypes; hardware fit and thermal tests pending.
   See PRINT-GUIDE.md. Panel mounts from Waveshare DWG: 125 x 65, M3.
   Print parts individually, never print assembly/exploded output. */
variant = 1; // [1:Line,2:Orbit,3:Gallery,4:Vault,5:Console]
part = "assembly"; // [assembly,exploded,body,bezel,lid,keeper,bridge,carrier,rail,spacer,ports,ports_usb_c,cassette,feet,coupon,acrylic_template]
acrylic_thickness = 1; // Confirmed by owner, 2026-10-05
panel_depth = 14.5; // Waveshare official dimension image
pilot = 2.6; // Pre-tap M3 or tune with coupon; do not force screws
keeper_pilot = 1.6; // M2 pilot; tune after coupon testing
clearance = 3.4;
// Provisional PCB envelope and adjustable hole pattern: measure the actual board.
pcb_length = 58;
pcb_width = 29;
pcb_thickness = 1.6;
pcb_hole_length = 52;
pcb_hole_width = 23;
pcb_standoff = 20;
$fn=40;
eps=0.04;
// width,height,body depth,corner radius,lens width,lens height,cable tray height
configs = [[190,110,82,5,164,84,14], [202,122,84,16,164,84,20],
           [206,156,84,8,180,130,20], [206,156,110,8,180,130,40],
           [202,122,96,7,164,84,30]];
style=is_undef(style_id) ? variant : style_id;
c=configs[style-1];
W=c[0]; H=c[1]; D=c[2]; R=c[3]; LW=c[4]; LH=c[5]; CH=c[6];
wall=3; bezel_t=6.5; lid_t=3;
// Clear opening exceeds entire nominal panel outline: no LED-edge loading.
window_w=161; window_h=81;
panel_front=8.5; panel_back=panel_front+panel_depth;
bridge_x=W/2-8;
corner_x=W/2-7; corner_y=H/2-7;
keeper_w=LW+10; keeper_h=LH+10;
keeper_z=3+acrylic_thickness+0.3;
ports_y=-H/2+21;
carrier_xy=[43,12]; cassette_xy=[-44,H>=150?36:12];
// Cassette nominal footprint78x72; split from right-hand PCB zone by3mm.
assert(style>=1 && style<=5);
assert(acrylic_thickness>0 && acrylic_thickness<=1.2,"Recess needs regeneration for thicker stock");
assert(keeper_z+2<=bezel_t);
assert(W<=210 && H<=210,"Bed margin exhausted");
assert(pcb_hole_length>=30 && pcb_hole_length<=64,"PCB holes exceed rail adjustment");
assert(pcb_hole_width>=0 && pcb_hole_width<=32,"PCB holes exceed carrier adjustment");
assert(pcb_length<=64 && pcb_width<=36,"PCB exceeds reserved wiring envelope");
assert(pcb_standoff>=20 && pcb_standoff<=24,"Recheck PCB/panel connector clearance");
label_chars = "ABCDEFGHIJKLMNOPQRSTUVWXYZ /";
label_rows = [[2, 5, 7, 5, 5], [6, 5, 6, 5, 6], [7, 4, 4, 4, 7], [6, 5, 5, 5, 6], [7, 4, 6, 4, 7], [7, 4, 6, 4, 4], [7, 4, 5, 5, 7], [5, 5, 7, 5, 5], [7, 2, 2, 2, 7], [1, 1, 1, 5, 7], [5, 5, 6, 5, 5], [4, 4, 4, 4, 7], [5, 7, 7, 5, 5], [5, 7, 7, 7, 5], [7, 5, 5, 5, 7], [7, 5, 7, 4, 4], [7, 5, 5, 7, 1], [6, 5, 6, 5, 5], [7, 4, 7, 1, 7], [7, 2, 2, 2, 2], [5, 5, 5, 5, 7], [5, 5, 5, 5, 2], [5, 5, 7, 7, 5], [5, 5, 2, 5, 5], [5, 5, 2, 2, 2], [7, 1, 2, 4, 7], [0, 0, 0, 0, 0], [1, 1, 2, 4, 4]];
function label_index(c, i=0) = i>=len(label_chars) ? -1 : label_chars[i]==c ? i : label_index(c,i+1);
module engraved_label(value, x, y, top, scale=0.65) {
    for(i=[0:len(value)-1]) let(index=label_index(value[i]))
        if(index>=0) for(row=[0:4],col=[0:2])
            if(floor(label_rows[index][row]/pow(2,2-col))%2==1)
                translate([x+(i*4+col)*scale,y+(4-row)*scale,top-0.6]) cube([scale-0.06,scale-0.06,0.7]);
}


module rr(w,h,r=2){ hull() for(x=[-1,1],y=[-1,1]) translate([x*(w/2-r),y*(h/2-r)]) circle(r=r); }
module outline(w=W,h=H,r=R){
    if(style==5) polygon([[-w/2+7,-h/2],[w/2-7,-h/2],[w/2,-h/2+7],[w/2,h/2-7],
                          [w/2-7,h/2],[-w/2+7,h/2],[-w/2,h/2-7],[-w/2,-h/2+7]]);
    else rr(w,h,r);
}
module slab(w,h,t,r=2){linear_extrude(t) rr(w,h,r);}
module outer(t){linear_extrude(t) outline();}
module hole(x,y,z,d,h){translate([x,y,z]) cylinder(d=d,h=h);}
module slot(x,y,z,length,d,h,angle=0){translate([x,y,z]) rotate([0,0,angle]) hull(){translate([-length/2,0,0]) cylinder(d=d,h=h);translate([length/2,0,0]) cylinder(d=d,h=h);}}
module corners(z,d,h){for(x=[-1,1],y=[-1,1]) hole(x*corner_x,y*corner_y,z,d,h);}
module keeper_outline(pad=0){
    union(){
        rr(keeper_w+2*pad,keeper_h+2*pad,1+pad);
        // Local screw ears preserve material without approaching corner fasteners.
        for(x=[-1,1],y=[-1,1]) translate([x*(LW/2+3),y*(LH/2-9)]) circle(r=4+pad);
    }
}
module bezel(){
    difference(){
        outer(bezel_t);
        translate([0,0,-eps]) slab(window_w,window_h,bezel_t+2*eps,.8);
        // Rear-load sheet into REMOVABLE bezel, then fit separate keeper.
        translate([0,0,3]) slab(LW+.8,LH+.8,4,style>=3&&style<=4?.2:1.2);
        translate([0,0,keeper_z]) linear_extrude(3) keeper_outline(.25);
        corners(-eps,clearance,bezel_t+2*eps);
        for(x=[-1,1],y=[-1,1]) hole(x*(LW/2+3),y*(LH/2-9),1.0,keeper_pilot,5.6);
    }
}
module keeper(){difference(){
    linear_extrude(2) keeper_outline();
    translate([0,0,-eps]) slab(window_w,window_h,3,.8);
    for(x=[-1,1],y=[-1,1]) hole(x*(LW/2+3),y*(LH/2-9),-eps,2.8,3);
}}
module body(){difference(){
    intersection(){
        outer(D);
        union(){
            difference(){outer(D);translate([0,0,-eps]) linear_extrude(D+2*eps) outline(W-2*wall,H-2*wall,max(1,R-wall));}
            // Full-height bosses avoid the previous unsupported elevated bosses.
            for(x=[-1,1],y=[-1,1]) hole(x*corner_x,y*corner_y,0,10,D);
            // Bridges carry panel by threaded REAR inserts; front stays untouched.
            for(x=[-1,1],y=[-1,1]) hull(){
                hole(x*bridge_x,y*32.5,0,9,panel_back-bezel_t);
                hole(x*(W/2-1),y*32.5,0,7,panel_back-bezel_t);
            }
        }
    }
    corners(-eps,pilot,12); corners(D-12,pilot,13);
    // Clearance for keeper screw heads up toØ5.5 x2.5mm, incl. assembly tolerance.
    for(x=[-1,1],y=[-1,1]) hole(x*(LW/2+3),y*(LH/2-9),-eps,6.2,2.8);
    for(x=[-1,1],y=[-1,1]) hole(x*bridge_x,y*32.5,panel_back-bezel_t-9,pilot,11);
    // Slots 3mm wide: short bridges at their roofs; no support inside cable bays.
    for(x=[-66:6:66],s=[-1,1])
        translate([x,s*H/2,D*.65]) cube([3,9,min(24,D*.28)],center=true);
    // Console: shallow external vertical fluting, wall never below2.2mm.
    if(style==5) for(z=[8:7:D-6],s=[-1,1])
        translate([s*(W/2-.35),0,z]) cube([.9,H-24,2],center=true);
}}
module bridge(){difference(){
    slab(2*bridge_x+8,12,3,2);
    for(x=[-1,1]){
        hole(x*bridge_x,0,-eps,clearance,4);
        slot(x*62.5,0,-eps,3,clearance,4);
    }
}}
mounts=[for(y=[-1,1]) [carrier_xy[0],carrier_xy[1]+y*27], for(y=[-1,1]) [cassette_xy[0],cassette_xy[1]+y*31]];
function vent_safe(x)=min([for(p=mounts) (abs(x-p[0])<6.5 && abs(H/2-17-p[1])<12) ? 0:1])==1;
module lid(){difference(){
    outer(lid_t);
    corners(-eps,clearance,4);
    translate([0,ports_y,-eps]) slab(120,20,4,2);
    for(x=[-1,1]) hole(x*65,ports_y,-eps,clearance,4);
    // Carrier and cassette both removable with accessible through-bolts.
    for(y=[-1,1]) hole(carrier_xy[0],carrier_xy[1]+y*27,-eps,clearance,4);
    for(y=[-1,1]) hole(cassette_xy[0],cassette_xy[1]+y*31,-eps,clearance,4);
    for(x=[-65:6:65]) if(vent_safe(x)) translate([x,H/2-17,-eps]) slab(3,13,4,1.4);
    for(x=[-60,-30],y=[H/2-33,H/2-26]) translate([x,y,-eps]) slab(12,2.6,4,.8);
    engraved_label("INGE / AFTER HOURS",-28,H/2-7,lid_t,.65);
}}
module ports(upgrade=false){difference(){
    slab(142,32,3,3);
    for(x=[-1,1]) hole(x*65,0,-eps,clearance,4);
    // Existing power lead and USB cable pass independently. Optional bulkheads later.
    translate([-34,0,-eps]) slab(22,14,4,2);
    if(upgrade) hole(34,0,-eps,12.4,4);
    else translate([34,0,-eps]) slab(32,18,4,2);
    // Two strap slots each side of each opening for internal cable restraint.
    for(x=[-48,-20,14,54]) translate([x,0,-eps]) slab(3,12,4,.8);
}}
module carrier(){difference(){
    union(){
        slab(90,60,3,3);
        for(x=[-1,1]) translate([x*39,0,3-eps]) slab(12,46,6+eps,2);
    }
    for(x=[-1,1]) {
        slot(x*39,0,-eps,32,clearance,11,90);
        // M3 nuts slide in bottom channels, closed by the lid after adjustment.
        translate([x*39,0,-eps]) slab(6.1,42,2.5+eps,1);
    }
    for(y=[-1,1]) hole(0,y*27,-eps,clearance,4);
    // Open centre: underside wires have free air rather than a solid heat trap.
    translate([0,0,-eps]) slab(64,40,4,2);
}}
module rail(){difference(){
    slab(88,10,3,2);
    for(x=[-1,1]){
        hole(x*39,0,-eps,clearance,4);
        slot(x*23.5,0,-eps,17,3.2,4);
    }
}}
module spacer(){difference(){cylinder(d=7,h=pcb_standoff);translate([0,0,-eps]) cylinder(d=3.2,h=pcb_standoff+1);}}
module cassette(){difference(){
    union(){
        slab(78,72,2.4,5);
        // Broad oval guide: R25 minimum guide-surface bend, open-sided for ribbon.
        // Smooth oval avoids winding cables around sharp posts.
        translate([0,0,2.4-eps]) difference(){
            slab(62,52,CH-2.4+eps,25);
            translate([0,0,-eps]) slab(58,48,CH+1,23);
        }
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

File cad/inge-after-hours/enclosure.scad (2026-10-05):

/* INGE / AFTER HOURS — dimensioned CONCEPT, not fit-approved.
   Millimetres. Set verified_dimensions only after measuring the real hardware.
   Default panel outline is evidenced by the photographed P2.5 / 80x160 moulding.
   ALL panel depth, PCB, holes, connector and fit values remain provisional.
   Parts: assembly, exploded, shell, lid, ports, carrier, clip, stand, coupon, front_spacer, acrylic_template.
   See README.md for assembly, print orientation and unresolved power topology. */

/* [Output] */
part = "assembly"; // [assembly, exploded, shell, lid, ports, carrier, clip, stand, coupon, front_spacer, acrylic_template]
verified_dimensions = false;
allow_prototype_export = false;
show_hardware = true;

/* [Panel - measure before printing] */
panel_w = 160;
panel_h = 80;
panel_depth = 15; // Rear structural edge, NOT highest cable/connector
panel_clearance = 0.4; // Per side
front_overlap = 0.6; // Check no LED is obscured

/* [Front acrylic - measure stock thickness] */
acrylic_thickness = 2;
acrylic_clearance = 0.3; // Lateral clearance per side and allowance for a soft pad
acrylic_border = 2; // Acrylic extends beyond panel outline on every edge
led_gap = 1.5; // Printed spacer between acrylic pocket and panel face
show_acrylic = true;

/* [Case] */
wall = 2.4;
front_thickness = 3;
rear_depth = 60; // Front surface to rear lid seat
lid_thickness = 3;
side_space = 8.6;
corner_radius = 4;
fit = 0.3;
screw_clearance = 3.3;
screw_pilot = 2.6; // Provisional printed pilot; pre-tap M3, fit-test first

/* [Replaceable rear connector plate - provisional hardware] */
port_plate_w = 92;
port_plate_h = 34;
port_plate_t = 3;
power_mount_d = 8; // Panel jack mounting thread, NOT barrel plug diameter
usb_open_w = 14;
usb_open_h = 7;
usb_mount_pitch = 24; // Selected USB-C panel extension flange, not USB standard
usb_mount_d = 3.3;

/* [Controller carrier - not measured] */
pcb_l = 58;
pcb_w = 29;
pcb_hole_l = 52;
pcb_hole_w = 23;
pcb_hole_d = 3.3;
pcb_standoff = 6;

/* [Hidden] */
$fn = 40;
eps = 0.05;
outer_w = panel_w + 2*(panel_clearance+side_space+wall);
outer_h = panel_h + 2*(panel_clearance+side_space+wall);
inner_w = outer_w - 2*wall;
inner_h = outer_h - 2*wall;
clip_x = panel_w/2 + panel_clearance + 4;
clip_y = panel_h/2 - 18;
acrylic_w = panel_w + 2*acrylic_border;
acrylic_h = panel_h + 2*acrylic_border;
acrylic_pocket_z = front_thickness + acrylic_thickness + acrylic_clearance;
panel_front_z = acrylic_pocket_z + led_gap;
clip_z = panel_front_z + panel_depth;
port_origin = [-32,-24];
carrier_origin = [39,11];
carrier_w = pcb_l + 22;
carrier_h = pcb_w + 16;
lid_screws = [for(x=[-1,1],y=[-1,1]) [x*(outer_w/2-5),y*(outer_h/2-5)]];
carrier_mounts = [for(x=[-1,1]) [x*(carrier_w/2-4),0]];

assert(panel_w > 100 && panel_h > 60, "Review case layout for smaller panels");
assert(front_overlap > 0 && front_overlap < 1.25, "Front lip may obscure LEDs");
assert(acrylic_thickness>=1 && acrylic_thickness<=4 && led_gap>=1,"Review acrylic thickness and LED gap");
assert(rear_depth > panel_front_z+panel_depth+pcb_standoff+18, "Insufficient rear cavity");
assert(part=="assembly" || part=="exploded" || part=="coupon" || part=="acrylic_template" || verified_dimensions || allow_prototype_export,
 "UNVERIFIED hardware: measure first or explicitly allow_prototype_export for labelled prototypes");
if (!verified_dimensions) echo("PROTOTYPE: hardware dimensions and assembled fit NOT verified");

// Small engraved pixel lettering avoids machine-dependent font substitution.
label_chars = "ABCDEFGHIJKLMNOPQRSTUVWXYZ /";
label_rows = [[2, 5, 7, 5, 5], [6, 5, 6, 5, 6], [7, 4, 4, 4, 7], [6, 5, 5, 5, 6], [7, 4, 6, 4, 7], [7, 4, 6, 4, 4], [7, 4, 5, 5, 7], [5, 5, 7, 5, 5], [7, 2, 2, 2, 7], [1, 1, 1, 5, 7], [5, 5, 6, 5, 5], [4, 4, 4, 4, 7], [5, 7, 7, 5, 5], [5, 7, 7, 7, 5], [7, 5, 5, 5, 7], [7, 5, 7, 4, 4], [7, 5, 5, 7, 1], [6, 5, 6, 5, 5], [7, 4, 7, 1, 7], [7, 2, 2, 2, 2], [5, 5, 5, 5, 7], [5, 5, 5, 5, 2], [5, 5, 7, 7, 5], [5, 5, 2, 5, 5], [5, 5, 2, 2, 2], [7, 1, 2, 4, 7], [0, 0, 0, 0, 0], [1, 1, 2, 4, 4]];
function label_index(c, i=0) = i>=len(label_chars) ? -1 : label_chars[i]==c ? i : label_index(c,i+1);
module engraved_label(value, x, y, top, scale=0.65) {
    for(i=[0:len(value)-1]) let(index=label_index(value[i]))
        if(index>=0) for(row=[0:4],col=[0:2])
            if(floor(label_rows[index][row]/pow(2,2-col))%2==1)
                translate([x+(i*4+col)*scale,y+(4-row)*scale,top-0.6]) cube([scale-0.06,scale-0.06,0.7]);
}

module rounded_rect(w,h,r) {
    hull() for(x=[-1,1],y=[-1,1]) translate([x*(w/2-r),y*(h/2-r)]) circle(r=r);
}
module slab(w,h,t,r=3) { linear_extrude(t) rounded_rect(w,h,r); }
module drill(x,y,z,d,h) { translate([x,y,z]) cylinder(d=d,h=h); }
module tie_anchor(x,y) {
    // Two shoulders and top bridge create a transverse zip-tie tunnel.
    translate([x,y,27]) difference() {
        cube([12,7,5],center=true);
        cube([7,9,2.2],center=true);
    }
}
module shell() {
    difference() {
        union() {
            difference() {
                slab(outer_w,outer_h,rear_depth,corner_radius);
                translate([0,0,front_thickness]) slab(inner_w,inner_h,rear_depth,2);
                translate([0,0,-eps]) slab(panel_w-2*front_overlap,panel_h-2*front_overlap,
                    front_thickness+2*eps,0.7);
            }
            // Continuous acrylic pocket fence, tied into the front frame.
            translate([0,0,front_thickness-eps]) difference() {
                slab(acrylic_w+5,acrylic_h+5,acrylic_thickness+acrylic_clearance+led_gap+eps,2);
                translate([0,0,-eps]) slab(acrylic_w+2*acrylic_clearance,acrylic_h+2*acrylic_clearance,10,1.3);
            }
            // Front corner locating stops leave room for the panel and avoid LEDs.
            for(x=[-1,1],y=[-1,1]) translate([x*(panel_w/2+panel_clearance+1),y*(panel_h/2-7),panel_front_z])
                cube([2,10,3],center=true);
            // Retaining-clip towers join the side wall and front frame.
            for(x=[-1,1],y=[-1,1]) hull() {
                translate([x*clip_x,y*clip_y,front_thickness-eps]) cylinder(r=4,h=clip_z-front_thickness+eps);
                translate([x*(inner_w/2-1),y*clip_y,front_thickness-eps]) cylinder(r=3,h=clip_z-front_thickness+eps);
            }
            // Lid screw bosses connect to both adjacent walls.
            for(p=lid_screws) translate([p[0],p[1],rear_depth-10]) cylinder(r=4.5,h=10);
            // Lower open power channel: shelf + inner lip, outer wall closes the lane.
            // Kept clear of the upper ribbon anchors and the ventilation slots.
            translate([-64,-inner_h/2,24]) cube([128,8.5,1.5]);
            translate([-64,-inner_h/2+7,25.45]) cube([128,1.5,5]);
            // Cable guides sit at the perimeter: upper ribbon, lower power pair.
            for(x=[-48,0,48],y=[-1,1]) tie_anchor(x,y*(inner_h/2-2));
        }
        // Lens and spacer insertion pocket also clears the inner edges of clip towers.
        translate([0,0,front_thickness]) slab(acrylic_w+2*acrylic_clearance,acrylic_h+2*acrylic_clearance,acrylic_thickness+acrylic_clearance+led_gap,1.3);
        for(x=[-1,1],y=[-1,1]) drill(x*clip_x,y*clip_y,clip_z-10,screw_pilot,12);
        for(p=lid_screws) drill(p[0],p[1],rear_depth-9,screw_pilot,11);
        // Aligned top/bottom slots, away from corner fasteners and tie anchors.
        for(x=[-66,-60,-54,-36,-30,-24,18,24,30,54,60,66],y=[-1,1])
            translate([x,y*outer_h/2,43]) cube([3,wall*3,18],center=true);
    }
}
module front_spacer() {
    // Broad edge support; no pressure on individual LEDs. Fit-check border first.
    difference() {
        slab(acrylic_w,acrylic_h,led_gap,1);
        translate([0,0,-eps]) slab(panel_w-2*front_overlap,panel_h-2*front_overlap,led_gap+2*eps,0.7);
    }
}
module acrylic_template() { rounded_rect(acrylic_w,acrylic_h,1); }
module acrylic_sheet() { slab(acrylic_w,acrylic_h,acrylic_thickness,1); }
module panel_clip() {
    difference() {
        translate([-3,0,0]) slab(16,8,2.4,1.4);
        drill(2,0,-eps,screw_clearance,3);
    }
}
module lid() {
    difference() {
        slab(outer_w,outer_h,lid_thickness,corner_radius);
        for(p=lid_screws) drill(p[0],p[1],-eps,screw_clearance,lid_thickness+2*eps);
        translate([port_origin[0],port_origin[1],-eps]) slab(76,20,lid_thickness+2*eps,2);
        for(s=[-1,1]) drill(port_origin[0]+s*(port_plate_w/2-5),port_origin[1],-eps,screw_clearance,lid_thickness+2*eps);
        for(p=carrier_mounts) drill(carrier_origin[0]+p[0],carrier_origin[1]+p[1],-eps,screw_clearance,lid_thickness+2*eps);
        engraved_label("INGE / AFTER HOURS",5,39,lid_thickness,0.65);
        // Exhaust section deliberately clear of the PCB and rear connector plate.
        for(x=[-70:6:-12]) translate([x,20,-eps]) slab(3,24,lid_thickness+2*eps,1.4);
    }
}
module ports() {
    difference() {
        slab(port_plate_w,port_plate_h,port_plate_t,3);
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

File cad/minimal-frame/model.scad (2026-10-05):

/* MINIMAL / FRAME — two printed parts, mm. Prototype fit must be checked.
   Panel loads from FRONT, bolts through the four integral rear mounting ears.
   Existing USB-C and barrel power sockets face directly out of the rear.
   See README.md. Hardware envelopes are illustrative, not extra print parts. */
part = "assembly"; // [assembly,exploded,frame,rear,fit_corner,board_gauge,acrylic_template,panel_mock,pcb_mock,usb_mock,power_mock]
panel_w = 160;
panel_h = 80;
panel_depth = 14.5;
panel_clearance = 0.35; // per side; close sliding fit, never a press fit
acrylic_t = 1;
acrylic_w = 164;
acrylic_h = 84;
wall = 2.4;
outer_w = 176;
outer_h = 96;
rear_z = 108; // direct USB-C: board length + panel connector clearance
pcb_l = 58; // provisional: measure actual board
pcb_w = 29;
pcb_t = 1.6;
rear_wall = 1.6;
pcb_slot = 2.2; // board thickness + 0.6mm total clearance
pcb_stop = 2.8; // PCB end position behind outer rear face
usb_open_x = 12;
usb_open_y = 20;
power_open_d = 13;
pcb_x = 51; // PCB lies in YZ; component face points toward +X
power_l = 35; // existing barrel-to-terminal adapter, provisional envelope
power_w = 16;
power_h = 14;
$fn = 40;
eps = 0.04;
front_lip = 1.6;
lens_seat = acrylic_t + 0.3;
panel_front = lens_seat + front_lip + 2.9;
panel_back = panel_front + panel_depth;
frame_depth = panel_back + 3;
rear_t = 1.8;
leg_h = rear_z - frame_depth;
cx = outer_w/2 - 4;
cy = outer_h/2 - 4;
power_x = -43;
power_y = 0;
assert(panel_w+2*panel_clearance<acrylic_w);
assert(panel_h+2*panel_clearance<acrylic_h);
assert(pcb_l<=62 && pcb_w<=33,"Recheck board guides and USB access for larger PCB");
assert(rear_z-(pcb_stop+pcb_l+6)>panel_back+20,"Increase rear depth for PCB guides/panel connector clearance");
assert(pcb_slot>pcb_t && pcb_slot<=pcb_t+1);
module rr(w,h,r=2){hull() for(x=[-1,1],y=[-1,1]) translate([x*(w/2-r),y*(h/2-r)]) circle(r=r);}
module slab(w,h,t,r=2){linear_extrude(t) rr(w,h,r);}
module hole(x,y,z,d,h){translate([x,y,z]) cylinder(d=d,h=h);}
module bar(x1,y1,x2,y2,w,t){hull(){hole(x1,y1,0,w,t);hole(x2,y2,0,w,t);}}
module perimeter(t,width=wall){difference(){slab(outer_w,outer_h,t,4);translate([0,0,-eps]) slab(outer_w-2*width,outer_h-2*width,t+2*eps,max(.5,4-width));}}
module front_frame(){difference(){
    union(){
        perimeter(frame_depth);
        // Four through-bolt bosses, outside the panel and acrylic.
        for(x=[-1,1],y=[-1,1]) hole(x*cx,y*cy,0,7,frame_depth);
        // Front ledge with a 45-degree underside, printed rear face down.
        difference(){
            slab(outer_w,outer_h,8.2,4);
            translate([0,0,-eps]) slab(panel_w+2*panel_clearance,panel_h+2*panel_clearance,lens_seat+front_lip+eps,.6);
            hull(){
                translate([0,0,lens_seat+front_lip]) slab(panel_w+2*panel_clearance,panel_h+2*panel_clearance,.05,.6);
                translate([0,0,8.2]) slab(outer_w-2*wall,outer_h-2*wall,.05,1.6);
            }
        }
        // Integral mounting ears, short panel bolts; these touch the print bed.
        for(x=[-1,1],y=[-1,1]) translate([0,0,panel_back])
            bar(x*62.5,y*32.5,x*(outer_w/2-wall/2),y*32.5,8,3);
        // Side guides are rooted in the rear face: no suspended cantilevers.
        for(x=[-1,1],y=[-1,1]) translate([x*(panel_w/2+panel_clearance+(outer_w/2-panel_w/2-panel_clearance)/2),y*18,(8.2+frame_depth)/2])
            cube([outer_w/2-panel_w/2-panel_clearance,5,frame_depth-8.2],center=true);
        for(x=[-1,1],y=[-1,1]) translate([x*30,y*(panel_h/2+panel_clearance+(outer_h/2-panel_h/2-panel_clearance)/2),(8.2+frame_depth)/2])
            cube([5,outer_h/2-panel_h/2-panel_clearance,frame_depth-8.2],center=true);
    }
    // Continuous loading path from the front down to the panel mounting ears.
    translate([0,0,-eps]) slab(panel_w+2*panel_clearance,panel_h+2*panel_clearance,panel_back+eps,.6);
    translate([0,0,-eps]) slab(acrylic_w+.6,acrylic_h+.6,lens_seat+eps,1.3);
    for(x=[-1,1],y=[-1,1]){
        hole(x*cx,y*cy,-eps,3.4,frame_depth+2*eps);
        hole(x*62.5,y*32.5,panel_back-eps,3.4,3+2*eps);
    }
}}
// Restrict guide shapes and bosses to the outer envelope.
module frame_assembled(){intersection(){front_frame();slab(outer_w,outer_h,frame_depth,4);}}
module frame_print(){translate([0,0,frame_depth]) rotate([180,0,0]) frame_assembled();}
module board_guides(){
    // PCB slides USB-end first down two grooves. One 3mm tie retains its far end.
    rail_end=pcb_stop+pcb_l+6;
    for(y=[-1,1]) difference(){
        union(){
            translate([pcb_x-2.2,y>0?pcb_w/2-.8:-pcb_w/2-3.5,rear_t])
                cube([6,4.3,rail_end-rear_t]);
            // Continuous thin fin connects each guide to the case side.
            translate([pcb_x+3.7,y*(pcb_w/2+2.4)-.8,rear_t])
                cube([outer_w/2-pcb_x-3.7,1.6,rail_end-rear_t]);
        }
        translate([pcb_x+(pcb_t-pcb_slot)/2,y>0?pcb_w/2-.85:-pcb_w/2-.3,pcb_stop])
            cube([pcb_slot,1.15,rail_end-pcb_stop+eps]);
        // Tie goes over the PCB's far edge, clear of its components.
        translate([pcb_x-2.3,y*(pcb_w/2+1.5)-1.6,pcb_stop+pcb_l+.2])
            cube([7.5,3.2,3.4]);
    }
}
module power_cradle(){
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

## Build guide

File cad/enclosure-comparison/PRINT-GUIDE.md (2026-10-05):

# Print and assembly guide — five enclosure kits

Dimensions and STL units are millimetres. This is a complete digital prototype
handoff; hardware fit, temperature and cable-pull checks require a real assembly.
Use one variant's files throughout. Each ZIP preserves the shared source beside
its variant folder, so `model.scad` can find `../family.scad` after extraction.

## Components and nominal space

- Waveshare P2.5 panel: nominal 160 × 80 × 14.5 mm, four outer rear M3 inserts at
  125 × 65 mm spacing. Source drawing evidence is in `evidence/`; confirm your
  panel's inserts and permissible screw engagement at the workshop.
- ESP32: provisional PCB 58 × 29 × 1.6 mm, nominal holes 52 × 23 mm apart. Rails
  slide on the carrier and PCB holes slide along the rails. Measure the board;
  the photograph proves neither these dimensions nor an M3-compatible hole size.
- Acrylic: 1 mm thick. Gallery/Vault accept 180 × 130 mm sheets; the other designs
  require the supplied 164 × 84 mm SVG cut outline, imported at 100% scale.
  SVG pages include a 1 mm margin all around (166 × 86 or 182 × 132 mm).
  The cut path has the stated sheet dimensions; do not resize the page to them.
- Existing power and USB leads pass through 22 × 14 mm and 32 × 18 mm rear
  openings. Check actual plug envelopes. Cable straps attach to the plate's slots.
- The panel gets a nominal 20 mm plugged-in connector reserve behind its rear
  face, apart from the mounting bridges. The controller bay reserves 64 × 36 ×
  38 mm, including underside jumpers. These are explicit allowances, not measured
  representations of connectors. Check every connector with its cable plugged in.

## Parts to print for ONE enclosure

| File in the chosen `stl/` folder | Quantity | Purpose and orientation |
| --- | ---: | --- |
| `bezel.stl` | 1 | Front face down; separately removable acrylic holder |
| `keeper.stl` | 1 | Flat; acrylic retaining ring |
| `body.stl` | 1 | Supplied Z=0 face down; open through shell |
| `lid.stl` | 1 | Flat; removable rear cover |
| `bridge.stl` | 2 | Flat; mounts panel by rear inserts |
| `carrier.stl` | 1 | Base down; adjustable ESP32 mounting frame |
| `rail.stl` | 2 | Flat; adjusts longitudinal PCB hole spacing |
| `spacer.stl` | 4 | Upright; 20 mm default wiring clearance under PCB |
| `cassette.stl` | 1 | Base down; removable oval cable guide |
| `ports.stl` | 1 | Flat; pass-through plate for existing cables |
| `feet.stl` | 2 | Supplied flat orientation; rotate when assembling |
| `coupon.stl` | 1 | Print FIRST; screw/acrylic/round-inlet fit gauges |
| `ports_usb_c.stl` | 0 by default | Optional substitute for `ports`, never an extra plate |

There are 17 installed printed pieces and one test coupon. Duplicate bridges,
rails, spacers and feet in the slicer according to the table; one STL is one piece.
The holes in the coupon run left-to-right 1.6, 1.8, 2.0, 2.2, 2.4, 2.6, 2.8, 3.0 and 3.4 mm.
The three open acrylic grooves are 1.0, 1.2 and 1.4 mm. The large round openings
are 12.2, 12.4 and 12.6 mm, intended only for the optional round USB adapter.
Check the rectangular plate openings with a test print of the actual plate.

## Hardware to bring

| Use | Quantity | Nominal fastener |
| --- | ---: | --- |
| Bezel to shell | 4 | M3 screw into prepared printed 2.6 mm pilot |
| Lid to shell | 4 | M3 screw into prepared printed 2.6 mm pilot |
| Bridges to shell seats | 4 | M3 screw into prepared printed 2.6 mm pilot |
| Panel to bridges | 4 | M3 screw into the panel's existing inserts |
| Acrylic keeper to bezel | 4 | M2 screw into prepared printed 1.6 mm pilot |
| Carrier to lid | 2 | M3 bolt + nut |
| Cassette to lid | 2 | M3 bolt + nut |
| Port plate to lid | 2 | M3 bolt + nut |
| Rails to carrier | 4 | M3 bolt + nut; nuts in carrier channels |
| PCB/spacers to rails | 4 | Bolt + nut matched to actual board holes, maximum M3 |

For the default M3-compatible PCB: 30 M3 screws/bolts, 14 M3 nuts and 4 M2 screws.
Add appropriate washers, soft cable straps/ties, non-slip pads and removable tape
for the cradle feet. Screw lengths are selected against real material stacks:
panel bolts cross a 3 mm bridge before entering the inserts; board bolts cross
PCB thickness + 20 mm spacer + 3 mm rail plus washer/nut allowance. Lid-mounted
parts have 3 mm lid + 3 mm plate/frame bases (cassette base: 2.4 mm). Check nuts
and washers clear wires and vents. Pilot bosses allow about 12 mm engagement at
front/rear, 9 mm at bridge seats; do not bottom screws or reach the electronics.
M2 keeper pilots begin 1 mm behind the front; leave that front wall intact.

The carrier channels are 6.1 mm wide and 2.5 mm deep. Measure your nuts; thicker
nuts need a revised channel. Four 5.6 × 2.4 mm M3 head envelopes are checked at
the panel mounts, bridge mounts, front, rear and PCB. Keeper heads are checked
at 5.5 × 2.5 mm; they must fit the shell reliefs. Other nut/head clearances need
a fit assembly. Pre-tap suitable printed pilots after coupon testing; do not
force metric screws into undersized printed holes.

## Print workflow

The largest footprint is 206 × 156 mm. All supplied orientations leave at least
5 mm brim space on an assumed 220 × 220 mm bed and stay below 250 mm height.
Use the workshop's validated printer/material profile. A 0.4 mm nozzle, 0.2 mm
layers, four perimeters and 15–20% infill are starting preferences. The included
`diagnostic-slicer.ini` is an inherited diagnostic reference, not a proven printer
profile; no slicing result or machine-ready G-code is claimed for this revision.

1. Print the coupon, carrier, one rail, one spacer and the default port plate.
   Confirm the screws, board hole size, nuts, acrylic thickness and plugged cables.
2. Confirm panel dimensions and mounting geometry against the real panel.
   Adjust CAD and regenerate if necessary; do not trim structural parts to force fit.
3. Slice the selected kit; inspect bridges over vents, nut channels and grooves.
   The shell has full-height corner bosses; vent roofs span only 3 mm. Local
   bridge/support choices depend on your printer and profile.
4. Print the remaining parts in the table, then clean and deburr the mating faces.

## Assembly order

1. Lay bezel front-down on a protected surface. Insert acrylic from the rear and
   fit the keeper with four M2 screws. The 0.3 mm thickness allowance can take a
   thin compliant edge pad after testing; the sheet should not rattle or bow.
2. Attach bezel to body using the four front M3 screws. The panel is held by its
   rear inserts, not compressed against acrylic. Nominal sheet-to-panel gap is
   4.5 mm; keeper-to-panel gap is 2.2 mm.
3. Attach the two bridges to the panel's outer rear inserts, then fasten their
   ends to the shell seats. Select panel screw lengths by permissible insert
   engagement. Leave all LED edges and solder joints unloaded.
4. Put nuts into the carrier channels. Fasten carrier to inside of lid, and fit
   the two rails against its raised pads. Slide rails to the measured PCB hole
   spacing, then tighten. Mount the board on four spacers with component side
   toward the lid; underside GPIO wiring faces the panel. See the exploded view.
5. Attach cassette and pass-through plate to lid. The plate is outside, covering
   the lid's broad opening; its cable openings face the outside. Retain the
   power/USB leads with soft straps through the adjacent slots. Avoid sharp edges
   and don't transfer cable pulls to the board's USB socket.
6. Route HUB75/jumpers in the middle compartment and power/service tails toward
   the rear plate. Gently loop spare cable around the cassette's oval guide and
   strap it loosely. The nominal guide's minimum bend radius is 25 mm, but each
   cable's actual bend requirement takes precedence. Do not tightly wind the
   HUB75 ribbon; leave its natural gentle bend and a service loop to open the lid.
7. Keep the ESP32 antenna away from dense cable bundles; inspect all clearances
   with cables plugged in. BOOT and EN are reached by removing the four rear
   screws; an external button actuator is not included.
8. Close the lid with four M3 screws. Fit two cradle feet near the side edges,
   their small lip at the front and large lip at the rear. Add pads and removable
   tape; verify stability with all cables attached.
9. Test display edges, USB upload, Wi-Fi, BOOT/EN access, cable retention, and
   temperature during sustained use. Follow the project's confirmed power wiring:
   keep external ESP32 5 V disconnected while powered from computer USB.

Bring the actual components to the workshop. Digital collision checks cannot
measure your board, determine permissible insert depth or prove thermal behaviour.

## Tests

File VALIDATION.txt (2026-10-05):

Validation performed on 2026-10-03

Pokémon sprites, the Crystal GIF gallery, cries, and Bluetooth audio are on the
`pokemon` branch. This log covers the modular panel, Wi-Fi, and browser display.

PASS: JavaScript RGB565 conversion, primaries, transparency, image placement,
      output size, and rejection of unexpected input dimensions.
PASS: C++ frame receiver with -Wall -Wextra -Werror, AddressSanitizer, and UBSan.
      Tested full frames in 1-byte, 37-byte, 1436-byte, and whole-frame chunks;
      little-endian colour decoding; short/oversized uploads; abort and recovery.
      LeakSanitizer was disabled because it cannot operate in this environment.
PASS: Syntax checks for embedded browser JavaScript, the Playwright test script,
      and Python helper scripts.

PASS: Full browser interaction test using workspace-local Playwright and existing
      local Chromium. Verified default sharp white text sends only 0x0000/0xFFFF,
      smooth mode retains edge shades, foreground/background selection works,
      sharp scrolling, RGB frame order, image upload, drawing, brightness,
      errors, Wi-Fi form, and mobile layout. Endpoints were simulated.
PASS: Codec regression tests include sharp/smooth text masking and colour output.
PASS: PlatformIO ESP32 firmware compilation after migration to src/ and include/.
      Environment: esp32dev, espressif32 6.12.0, Arduino core 2.0.17,
      Adafruit GFX 1.12.6, HUB75 DMA Display 3.0.15.
      Automatic embedded UI generation ran successfully during the build.
      Static RAM: 51,280 / 327,680 bytes (15.6%).
      Flash: 851,057 / 1,310,720 bytes (64.9%).
      Firmware artifact: .pio/build/esp32dev/firmware.bin.
PASS: Existing C++ frame-protocol test rerun with -std=c++11 -Wall -Wextra -Werror.
PASS: Existing JavaScript codec test rerun; build scripts pass Python syntax checks.
PASS: USB firmware upload and device-side acknowledgements for RGB, full-white,
      and static Hello diagnostics on the connected ESP32.
PASS: Wi-Fi provisioning into device preferences and reconnection after restoring
      Matrix Studio and resetting the ESP32, confirmed through serial output.
PASS: Timing comparison firmware builds and uploads successfully.
      Verified automatic A-to-B switching, pause for a full 12-second interval,
      manual progression through A-J and wraparound, stop acknowledgement,
      and restart into the running A-J sweep.
      Static RAM: 51,312 bytes; flash: 854,593 bytes.
OBSERVED: User reports J flickers on many columns; I is best, with slight residual
          ghosting. I and J differ only in clock GPIO drive strength.
PASS: Focused comparison firmware builds and uploads successfully.
      Startup profile I confirmed over USB: 5 MHz, phase false, blanking 4,
      clock drive level 1; calculated startup refresh 131 Hz.
      Verified automatic I-to-K switching, pause acknowledgement, manual L/M/I
      progression and wraparound, stop and restart. Serial acknowledgements
      confirm the requested clock and other signal drive settings for each test.
      Left the focused I/K/L/M sweep running (12 seconds per profile).
OBSERVED: Focused comparison ranking reported by user: K best, followed by I;
          L and M clearly bad. Retain normal drive on non-clock panel signals.
PASS: Profile K made the startup default; firmware built and uploaded.
      Confirmed after reset over USB: 5 MHz, phase false, blanking 4, clock
      drive level 0, calculated refresh 131 Hz. Static white Hello acknowledged
      and left displayed with the sweep off.
      Static RAM: 51,320 bytes; flash: 855,165 bytes.
OBSERVED: User still sees a slight one-column shifted ghost with K.
          Signal ringing is a hypothesis, not a measured waveform.
PASS: Updated browser renderer and clock-only comparison firmware built and
      uploaded. Static RAM: 51,320 bytes; flash: 856,573 bytes.
      Startup K verified after reset. Focused K/N/O/P sweep verified over USB:
      automatic K-to-N advance, pause acknowledgement, manual O/P/K progression,
      wraparound, stop and restart. All retain clock drive 0, blanking 4 and
      non-clock signal drive 3. Left the 12-second comparison running.
PENDING: User visual comparison of K/N/O/P and physical browser white text.
OBSERVED: User reports N best and requests much slower clock trials.
PASS: Startup default changed to N; slow-clock firmware built and uploaded.
      Static RAM: 51,320 bytes; flash: 856,729 bytes.
      Reset confirmed startup N at 4 MHz, clock drive 0, phase false, blanking 4,
      with calculated scan refresh 105 Hz.
      Verified automatic N-to-Q advance, pause, manual R/S/N progression,
      wraparound, stop and restart. Left N/Q/R/S cycling every 12 seconds.
      Clock trials: 4, 2, 1 and 0.5 MHz. Estimated scan refresh: 105, 52.5,
      26.2 and 13.1 Hz respectively; these are calculations, not measurements.
OBSERVED: User reports N best again after the N/Q/R/S slow-clock comparison.
          Retain N as the operating and startup setting. Complete removal of
          the remaining copies is unconfirmed.
PASS: Reset reconfirmed startup N at 4 MHz and calculated refresh 105 Hz.
      Comparison stopped; static white Hello acknowledged and left displayed.
OBSERVED: User reports pale image areas purple, then clarifies the tint is only
          visible in photos. Camera capture timing is a separate possible cause.
FOUND: Driver was compiled with an eight-bit CIE table but configured with six
       DMA bitplanes. Reproduced cream RGB(240,230,220) emitting six-bit values
       (26,4,47) instead of the matching table's (54,48,43). Full white emits
       (63,63,63) in both cases, hiding the mismatch in endpoint tests.
PASS: Added global PIXEL_COLOR_DEPTH_BITS=6 build flag, matching runtime depth,
      and compile-time check. Actual library LUT regression verifies monotonic
      output for all 256 input levels, no discarded bits, black/white endpoints,
      and preservation of cream channel ordering.
PASS: Firmware rebuilt (including HUB75 library), uploaded and verified after
      reset: startup N, 105 Hz calculated refresh, compiled/runtime depth 6 bits.
      Direct RGB888 grayscale/pastel diagnostic acknowledged and left displayed.
      Static RAM: 51,320 bytes; flash: 857,329 bytes.
PENDING: User visual assessment of images after the fix. Photo-only tint may
         remain; no camera waveform or exposure timing was measured.
OBSERVED: User reports substantially improved borders/contours after the matched
          six-bit colour fix and requests keeping it. Some areas still look greenish.
PASS: Added direct RGB888/RGB565 purple comparison and matching browser chart.
      Codec and actual driver LUT tests verify purple does not gain green.
      Browser regression verifies all 2048 uploaded chart pixels against the
      expected RGB565 values, plus existing browser controls and scrolling.
PASS: Firmware built and uploaded; reset confirms N at 4 MHz, calculated refresh
      105 Hz, matching six-bit table/DMA. Purple comparison acknowledged over USB
      and left displayed. Static RAM: 51,320 bytes; flash: 858,201 bytes.
PENDING: User comparison of purple columns on both panel halves and browser
         preview. The new green tint's cause is unconfirmed; no channel swap or
         calibration has been applied without evidence.
OBSERVED: User confirms direct RGB bands display RED, BLUE, GREEN instead of
          RED, GREEN, BLUE. This establishes swapped green/blue channels.
CHANGE: Corrected driver pins for both halves: G1=27, B1=26, G2=13, B2=12.
        Retained R1=25, R2=14, matching six-bit LUT/DMA and N timing at 4 MHz.
PASS: Firmware compilation and USB upload after the mapping correction.
      Static RAM: 51,320 bytes; flash: 858,297 bytes.
PASS: USB reset confirms corrected R/G/B pins on both halves, six-bit colour
      depth and startup N at 4 MHz (calculated refresh 105 Hz). RGB and purple
      diagnostics acknowledged; purple comparison left displayed.
PENDING: User visual confirmation of corrected primary colours.
NOT RUN: Actual HTTP multipart processing validation on physical hardware.

The provided browser test uses simulated endpoints and would not, by itself,
validate the ESP32 WebServer implementation. Hardware validation steps are in README.md.

Validation performed on 2026-10-04 — live display redesign

PASS: Six live layouts (two per mode), six palettes, and independent motion.
      972 host-rendered firmware/browser pixel comparisons covering all layouts,
      palettes, motion settings, loading/error/unconfigured states, stale data,
      negative/zero temperatures, weather icons, and long accented labels.
PASS: Actual ArduinoJson firmware parsers tested on host: Open-Meteo units before
      current values, formatted YouTube JSON, zero and hidden counts, missing and
      malformed values, overflow, empty results, geocoding and API failures.
PASS: Palette inheritance/override isolation, legacy theme migration, saved/off
      mode restoration, retry intervals, timer rollover, reconnect invalidation,
      and discarding superseded worker results.
PASS: Existing frame protocol, RGB565 codec, panel colour-table regressions.
PASS: Browser interactions, saved appearance reload, palette isolation, six layout
      controls, motion settings, refresh requests, loading/error/stale UI, and
      390-pixel mobile layout. These browser endpoints are simulated.
PASS: PlatformIO firmware build and USB upload to /dev/cu.usbserial-0001.
      Pinned ArduinoJson 6.21.5. Background network worker uses bounded request
      and result queues; panel rendering/preferences remain on the main loop.
PASS: On real hardware, weather reports Toulouse at 20 C. YouTube returns channel
      Cosmic Hippo, 27.5K subscribers, 10.7M views, and 119 videos. These are observed
      values at validation time, not fixed expectations.
PASS: Real /api/live theme isolation and rejected invalid request without partial
      setting changes; mode switching through weather, YouTube, and clock.
PASS: Real simultaneous service refresh requests with responsive /api/status;
      max latency 0.220 seconds across ten requests while refresh was in flight.
PASS: USB reset restores stopped mode and appearance; a second reset restores
      YouTube mode and both services reach ready. Original mode and appearance
      restored after the test. Free heap after successful requests: 174,696 bytes.
PASS: Startup serial output retains profile N, 4 MHz, 105 Hz calculated refresh,
      and matching six-bit colour depth.
PENDING: Human visual assessment of the physical layouts/animation and remaining
         ghosting. Preview images are not measurements of the physical LEDs.
NOT RUN: Physical network outage/recovery test or direct BOOT-button press in this
         session; scheduling/reconnect state transitions have host-test coverage.

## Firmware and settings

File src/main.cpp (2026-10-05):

// Classic ESP32-WROOM + one Waveshare 64x32 HUB75 panel.
// Build and upload with PlatformIO; the browser UI is embedded from include/.
#include <Arduino.h>
#include <WiFi.h>
#include <WebServer.h>
#include <ESPmDNS.h>
#include <Preferences.h>
#include <esp_system.h>
#include <driver/gpio.h>
#include <rom/gpio.h>
#include <soc/gpio_sig_map.h>
#include <ESP32-HUB75-MatrixPanel-I2S-DMA.h>
#include "FrameProtocol.h"
#include "live.h"
#include "GiftState.h"
#include "web_ui.h"

static_assert(PIXEL_COLOR_DEPTH_BITS == 6,
              "Compile the HUB75 library with the same six-bit depth as the DMA buffer.");

WebServer server(80);
Preferences settings;
MatrixPanel_I2S_DMA* panel = nullptr;
MatrixProtocol::FrameReceiver incomingFrame;
String hostname, apName, apPassword, savedSSID, savedPassword;
bool apRunning = false, wasConnected = false, mdnsRunning = false;
bool connecting = false, changeWiFiPending = false, receivedContent = false;
uint32_t connectStarted = 0, changeWiFiAt = 0, framesReceived = 0;
uint8_t brightness = 30;
unsigned uploadFiles = 0;
gpio_drive_cap_t clockDrive = GPIO_DRIVE_CAP_0;
bool runtimeClockPhase = false;

enum SignalDriveMode : uint8_t { SIGNALS_DEFAULT, CONTROL_SOFT, ALL_SOFT };
SignalDriveMode signalDriveMode = SIGNALS_DEFAULT;

struct TimingProfile {
  char id;
  bool phase;
  uint8_t blanking;
  gpio_drive_cap_t drive;
  uint8_t divider;
  SignalDriveMode signals;
};

// Classic ESP32, pinned HUB75 library: 80 MHz / (divider * 2).
// Divider 4 is its normal 10 MHz output; divider 8 gives a 5 MHz trial.
const TimingProfile timingProfiles[] = {
  {'A', false, 4, GPIO_DRIVE_CAP_2, 4, SIGNALS_DEFAULT},
  {'B', false, 4, GPIO_DRIVE_CAP_2, 8, SIGNALS_DEFAULT},
  {'C', true,  4, GPIO_DRIVE_CAP_2, 4, SIGNALS_DEFAULT},
  {'D', true,  4, GPIO_DRIVE_CAP_2, 8, SIGNALS_DEFAULT},
  {'E', false, 2, GPIO_DRIVE_CAP_2, 4, SIGNALS_DEFAULT},
  {'F', false, 2, GPIO_DRIVE_CAP_2, 8, SIGNALS_DEFAULT},
  {'G', true,  2, GPIO_DRIVE_CAP_2, 4, SIGNALS_DEFAULT},
  {'H', true,  2, GPIO_DRIVE_CAP_2, 8, SIGNALS_DEFAULT},
  {'I', false, 4, GPIO_DRIVE_CAP_1, 8, SIGNALS_DEFAULT},
  {'J', false, 4, GPIO_DRIVE_CAP_3, 8, SIGNALS_DEFAULT},
  {'K', false, 4, GPIO_DRIVE_CAP_0, 8, SIGNALS_DEFAULT},
  {'L', false, 4, GPIO_DRIVE_CAP_1, 8, CONTROL_SOFT},
  {'M', false, 4, GPIO_DRIVE_CAP_1, 8, ALL_SOFT},
  {'N', false, 4, GPIO_DRIVE_CAP_0, 10, SIGNALS_DEFAULT},
  {'O', true,  4, GPIO_DRIVE_CAP_0, 8, SIGNALS_DEFAULT},
  {'P', true,  4, GPIO_DRIVE_CAP_0, 10, SIGNALS_DEFAULT},
  {'Q', false, 4, GPIO_DRIVE_CAP_0, 20, SIGNALS_DEFAULT},
  {'R', false, 4, GPIO_DRIVE_CAP_0, 40, SIGNALS_DEFAULT},
  {'S', false, 4, GPIO_DRIVE_CAP_0, 80, SIGNALS_DEFAULT},
};
constexpr size_t TIMING_PROFILE_COUNT = sizeof(timingProfiles) / sizeof(timingProfiles[0]);
const size_t focusedProfiles[] = {13, 16, 17, 18}; // N, Q, R, S.
constexpr size_t FOCUSED_PROFILE_COUNT = sizeof(focusedProfiles) / sizeof(focusedProfiles[0]);
const TimingProfile STARTUP_TIMING = {'N', false, 4, GPIO_DRIVE_CAP_0, 10, SIGNALS_DEFAULT};
constexpr uint32_t TIMING_TEST_INTERVAL_MS = 12000;
TimingProfile timingBeforeSweep = STARTUP_TIMING;
bool timingSweepActive = false, timingSweepPaused = false;
bool focusedSweep = false;
size_t timingSweepPosition = 0;
size_t timingProfileIndex = 0;
uint32_t timingProfileStarted = 0;

void applyClockDrive(gpio_drive_cap_t drive) {
  const gpio_num_t clockPin = static_cast<gpio_num_t>(panel->getCfg().gpio.clk);
  if (gpio_set_drive_capability(clockPin, drive) != ESP_OK) {
    Serial.println("Could not set panel clock drive strength.");
    return;
  }
  clockDrive = drive;
  Serial.println("Panel clock drive level: " + String(int(drive)));
}

void applySignalDrive(SignalDriveMode mode) {
  const auto& gpio = panel->getCfg().gpio;
  const int8_t pins[] = {gpio.r1, gpio.g1, gpio.b1, gpio.r2, gpio.g2, gpio.b2,
                         gpio.a, gpio.b, gpio.c, gpio.d, gpio.e, gpio.lat, gpio.oe};
  bool success = true;
  for (const int8_t pin : pins) {
    if (pin < 0) continue;
    const bool soft = mode == ALL_SOFT ||
                      (mode == CONTROL_SOFT && (pin == gpio.lat || pin == gpio.oe));
    success &= gpio_set_drive_capability(static_cast<gpio_num_t>(pin),
                                        soft ? GPIO_DRIVE_CAP_1 : GPIO_DRIVE_CAP_3) == ESP_OK;
  }
  if (success) signalDriveMode = mode;
  else Serial.println("Could not set panel signal drive strength.");
}

String jsonString(const String& value) {
  String out = "\"";
  for (size_t i = 0; i < value.length(); ++i) {
    unsigned char c = value[i];
    if (c == '\"' || c == '\\') { out += '\\'; out += char(c); }
    else if (c < 32) { char esc[7]; snprintf(esc, sizeof(esc), "\\u%04x", c); out += esc; }
    else out += char(c);
  }
  return out + "\"";
}

void sendJSON(int code, const String& body) {
  server.sendHeader("Cache-Control", "no-store");
  server.send(code, "application/json", body);
}

bool isControlRequest() {
  // Custom header prevents ordinary cross-site forms from changing the display.
  // This is not user authentication: other clients on the LAN can control it.
  return server.header("X-Matrix-Control") == "1";
}

bool requireControlRequest() {
  if (isControlRequest()) return true;
  sendJSON(403, "{\"error\":\"Missing X-Matrix-Control header\"}");
  return false;
}

void showMessage(const char* text) {
  if (receivedContent) return;
  panel->clearScreen();
  panel->setTextSize(1);
  panel->setTextColor(panel->color565(70, 180, 220));
  panel->setCursor(2, 12);
  panel->print(text);
  panel->flipDMABuffer();
}

void showHardwareColorTest() {
  liveHold();
  // Drive RGB888 directly to isolate panel/wiring faults from browser encoding.
  for (int16_t y = 0; y < 32; ++y) {
    for (int16_t x = 0; x < 64; ++x) {
      const bool white = y >= 24;
      panel->drawPixelRGB888(x, y,
                            white || x < 21 ? 255 : 0,
                            white || (x >= 21 && x < 42) ? 255 : 0,
                            white || x >= 42 ? 255 : 0);
    }
  }
  panel->flipDMABuffer();
  receivedContent = true;
  Serial.println("Hardware RGB test: RED | GREEN | BLUE, with a WHITE strip on the bottom 8 rows.");
  Serial.println("G1=GPIO27 B1=GPIO26 G2=GPIO13 B2=GPIO12; brightness=" + String(brightness));
}

void showHardwareWhiteTest() {
  liveHold();
  panel->fillScreenRGB888(255, 255, 255);
  panel->flipDMABuffer();
  receivedContent = true;
  Serial.println("Hardware white test: all 64x32 pixels WHITE; brightness=" + String(brightness));
}

void showHardwarePaletteTest() {
  liveHold();
  const uint8_t grays[] = {0, 32, 64, 96, 128, 180, 220, 255};
  const uint8_t pastels[][3] = {{240, 230, 220}, {255, 240, 200}, {240, 200, 200},
                              {200, 240, 200}, {200, 200, 240}, {200, 240, 240},
                              {240, 200, 240}, {255, 255, 255}};
  for (int16_t y = 0; y < 32; ++y) {
    for (int16_t x = 0; x < 64; ++x) {
      const size_t swatch = x / 8;
      if (y < 16) panel->drawPixelRGB888(x, y, grays[swatch], grays[swatch], grays[swatch]);
      else panel->drawPixelRGB888(x, y, pastels[swatch][0], pastels[swatch][1], pastels[swatch][2]);
    }
  }
  panel->flipDMABuffer();
  receivedContent = true;
  Serial.println("Hardware palette test: top BLACK to WHITE grayscale; bottom CREAM, PALE YELLOW, RED, GREEN, BLUE, CYAN, MAGENTA, WHITE.");
}

void showHardwareTextTest() {
  liveHold();
  panel->clearScreen();
  panel->setTextWrap(false);
  panel->setTextSize(1);
  panel->setTextColor(panel->color565(255, 255, 255));
  panel->setCursor(2, 12);
  panel->print("Hello");
  panel->flipDMABuffer();
  receivedContent = true;
  Serial.println("Hardware text test: static WHITE Hello on BLACK; brightness=" + String(brightness));
}

void showHardwarePurpleTest() {
  liveHold();
  const uint8_t colors[][3] = {{255, 0, 0}, {0, 255, 0}, {0, 0, 255}, {255, 0, 255},
                             {128, 0, 192}, {64, 0, 96}, {176, 144, 224}, {255, 255, 255}};
  for (int16_t y = 0; y < 32; ++y) {
    for (int16_t x = 0; x < 64; ++x) {
      const auto& color = colors[x / 8];
      if (y < 16) panel->drawPixelRGB888(x, y, color[0], color[1], color[2]);
      else panel->drawPixel(x, y, panel->color565(color[0], color[1], color[2]));
    }
  }
  panel->flipDMABuffer();
  receivedContent = true;
  Serial.println("Hardware purple test: RED GREEN BLUE MAGENTA PURPLE DARK-PURPLE LAVENDER WHITE.");
  Serial.println("Top=direct RGB888; bottom=RGB565 like browser uploads. Magenta/purple/dark-purple have zero green input.");
}

void applyTimingProfile(const TimingProfile& profile) {
  // Temporarily blank both buffers while changing the clock routing and divider.
  panel->setBrightness8(0);
  const int clockSignal = ESP32_I2S_DEVICE == I2S_NUM_0 ? I2S0O_WS_OUT_IDX : I2S1O_WS_OUT_IDX;
  gpio_matrix_out(panel->getCfg().gpio.clk, clockSignal, profile.phase, false);
  getDev()->clkm_conf.clkm_div_num = profile.divider;
  runtimeClockPhase = profile.phase;
  panel->setLatBlanking(profile.blanking);
  applySignalDrive(profile.signals);
  applyClockDrive(profile.drive);
}

void showTimingProfile() {
  const TimingProfile& profile = timingProfiles[timingProfileIndex];
  applyTimingProfile(profile);
  panel->clearScreen();
  panel->setTextWrap(false);
  panel->setTextSize(1);
  panel->setTextColor(panel->color565(255, 255, 255));
  panel->setCursor(2, 0);
  panel->print("TEST ");
  panel->print(profile.id);
  panel->setCursor(2, 12);
  panel->print("Hello");
  panel->setCursor(2, 24);
  panel->print("Hello");
  panel->drawFastVLine(48, 12, 20, panel->color565(255, 255, 255));
  panel->flipDMABuffer();
  panel->setBrightness8(brightness);
  receivedContent = true;
  timingProfileStarted = millis();
  // The DMA chain stays unchanged during the sweep, so scan refresh scales
  // directly with clock frequency. This is an estimate, not a measurement.
  const float estimatedRefresh = float(panel->calculated_refresh_rate) *
                                 STARTUP_TIMING.divider / profile.divider;
  Serial.printf("TIMING TEST %c: clock=%.2f MHz phase=%u blanking=%u drive=%u signals=%u brightness=%u estimated_refresh=%.1f Hz\n",
                profile.id, 40.0 / profile.divider, unsigned(profile.phase),
                unsigned(profile.blanking), unsigned(profile.drive), unsigned(profile.signals),
                unsigned(brightness), double(estimatedRefresh));
}

void startTimingSweep(bool focused = false) {
  liveHold();
  if (!timingSweepActive) {
    timingBeforeSweep = {'-', runtimeClockPhase, panel->getCfg().latch_blanking,
                         clockDrive, uint8_t(getDev()->clkm_conf.clkm_div_num), signalDriveMode};
  }
  timingSweepActive = true;
  timingSweepPaused = false;
  focusedSweep = focused;
  timingSweepPosition = 0;
  timingProfileIndex = focused ? focusedProfiles[0] : 0;
  Serial.println(focused
                 ? "Slow-clock sweep: N,Q,R,S, 12 seconds each. P=pause/resume N=next X=stop."
                 : "Timing sweep: tests A-S, 12 seconds each, repeating. P=pause/resume N=next X=stop.");
  showTimingProfile();
}

void stopTimingSweep(bool showText = false) {
  if (!timingSweepActive) return;
  timingSweepActive = false;
  timingSweepPaused = false;
  applyTimingProfile(timingBeforeSweep);
  if (showText) showHardwareTextTest();
  panel->setBrightness8(brightness);
  Serial.println("Timing sweep stopped; previous timing restored.");
}

void nextTimingProfile() {
  timingSweepPosition = (timingSweepPosition + 1) %
                        (focusedSweep ? FOCUSED_PROFILE_COUNT : TIMING_PROFILE_COUNT);
  timingProfileIndex = focusedSweep ? focusedProfiles[timingSweepPosition] : timingSweepPosition;
  showTimingProfile();
}

void updateTimingSweep() {
  if (timingSweepActive && !timingSweepPaused &&
      uint32_t(millis() - timingProfileStarted) >= TIMING_TEST_INTERVAL_MS) {
    nextTimingProfile();
  }
}

void startSetupAP() {
  if (apRunning) return;
  WiFi.mode(WIFI_AP_STA);
  apRunning = WiFi.softAP(apName.c_str(), apPassword.c_str());
  if (!apRunning) { Serial.println("Setup Wi-Fi failed to start. Reset the ESP32."); return; }
  Serial.println("\n--- Wi-Fi setup ---");
  Serial.println("Network: " + apName);
  Serial.println("Password: " + apPassword);
  Serial.println("Open http://" + WiFi.softAPIP().toString());
  showMessage("SETUP");
}

void beginHomeWiFi() {
  if (savedSSID.isEmpty()) { connecting = false; startSetupAP(); return; }
  WiFi.disconnect();
  WiFi.setAutoReconnect(true);
  WiFi.begin(savedSSID.c_str(), savedPassword.c_str());
  connectStarted = millis();
  connecting = true;
  Serial.println("Connecting to " + savedSSID + " (2.4 GHz)...");
}

void updateWiFi() {
  if (changeWiFiPending && int32_t(millis() - changeWiFiAt) >= 0) {
    changeWiFiPending = false;
    startSetupAP(); // Retain a recovery path while trying new credentials.
    beginHomeWiFi();
  }
  bool connected = WiFi.status() == WL_CONNECTED;
  if (connected && !wasConnected) {
    connecting = false;
    if (mdnsRunning) MDNS.end();
    mdnsRunning = MDNS.begin(hostname.c_str());
    if (mdnsRunning) MDNS.addService("http", "tcp", 80);
    Serial.println("\nOpen http://" + WiFi.localIP().toString());
    Serial.println("Also try http://" + hostname + ".local");
    showMessage("READY");
  } else if (!connected && wasConnected) {
    if (mdnsRunning) { MDNS.end(); mdnsRunning = false; }
    connecting = true;
    connectStarted = millis();
  }
  if (!connected && connecting && millis() - connectStarted > 20000) {
    startSetupAP();
    connecting = false;
  }
  wasConnected = connected;
}

void statusRoute() {
  const bool connected = WiFi.status() == WL_CONNECTED;
  String out = "{\"width\":64,\"height\":32,\"connected\":";
  out += connected ? "true" : "false";
  out += ",\"ip\":" + jsonString(connected ? WiFi.localIP().toString() : "");
  out += ",\"hostname\":" + jsonString(hostname + ".local");
  out += ",\"ssid\":" + jsonString(savedSSID);
  out += ",\"ap\":" + jsonString(apRunning ? apName : "");
  out += ",\"brightness\":" + String(brightness);
  out += ",\"frames\":" + String(framesReceived);
  out += ",\"freeHeap\":" + String(ESP.getFreeHeap());
  out += liveStatusJson();
  out += "}";
  sendJSON(200, out);
}

void uploadFrame() {
  HTTPUpload& upload = server.upload();
  if (upload.status == UPLOAD_FILE_START) {
    ++uploadFiles;
    if (uploadFiles == 1) incomingFrame.start();
    if (uploadFiles != 1 || upload.name != "frame" || !isControlRequest()) incomingFrame.reject();
  } else if (upload.status == UPLOAD_FILE_WRITE) {
    incomingFrame.append(upload.buf, upload.currentSize);
  } else if (upload.status == UPLOAD_FILE_END) {
    incomingFrame.finish();
  } else if (upload.status == UPLOAD_FILE_ABORTED) {
    incomingFrame.reject();
    uploadFiles = 0;
  }
}

void finishFrame() {
  const bool valid = uploadFiles == 1 && incomingFrame.valid();
  uploadFiles = 0;
  if (!requireControlRequest()) return;
  if (!valid) {
    sendJSON(400, "{\"error\":\"Upload one frame file of exactly 4096 RGB565-LE bytes\"}");
    return;
  }
  stopTimingSweep();
  liveHold();
  for (size_t y = 0; y < MatrixProtocol::HEIGHT; ++y)
    for (size_t x = 0; x < MatrixProtocol::WIDTH; ++x)
      panel->drawPixel(x, y, incomingFrame.pixel(y * MatrixProtocol::WIDTH + x));
  panel->flipDMABuffer();
  receivedContent = true;
  ++framesReceived;
  sendJSON(200, "{\"ok\":true,\"frames\":" + String(framesReceived) + "}");
  incomingFrame.reject();
}

void brightnessRoute() {
  if (!requireControlRequest()) return;
  String value = server.arg("value");
  bool valid = value.length() >= 1 && value.length() <= 3;
  for (size_t i = 0; i < value.length(); ++i) valid &= value[i] >= '0' && value[i] <= '9';
  int number = value.toInt();
  if (!valid || number > 255) { sendJSON(400, "{\"error\":\"Brightness must be 0 to 255\"}"); return; }
  stopTimingSweep();
  brightness = uint8_t(number);
  liveSetBrightness(brightness);
  sendJSON(200, "{\"ok\":true}");
}

void wifiRoute() {
  if (!requireControlRequest()) return;
  String ssid = server.arg("ssid"), password = server.arg("password");
  if (ssid.isEmpty() || ssid.length() > 32 || password.length() > 63 || password.length() < 8) {
    sendJSON(400, "{\"error\":\"Use a 1-32 byte network name and an 8-63 character Wi-Fi password\"}");
    return;
  }
  // Preferences survives power loss; passwords are never included in API responses.
  const bool stored = settings.putString("ssid", ssid) > 0 &&
                      settings.putString("password", password) > 0;
  if (!stored) { sendJSON(500, "{\"error\":\"Could not save Wi-Fi settings\"}"); return; }
  savedSSID = ssid;
  savedPassword = password;
  changeWiFiPending = true;
  changeWiFiAt = millis() + 500;
  sendJSON(200, "{\"ok\":true,\"message\":\"Saved; connecting now. Watch the connection status.\"}");
}

void liveRoute() {
  if (!requireControlRequest()) return;
  String error;
  LiveRequest request;
  request.mode = server.arg("mode"); request.theme = server.arg("theme");
  request.target = server.arg("target"); request.palette = server.arg("palette");
  request.layout = server.arg("layout"); request.motion = server.arg("motion");
  request.city = server.arg("city"); request.key = server.arg("key");
  request.refresh = server.arg("refresh"); request.locate = server.hasArg("locate");
  if (!liveConfigure(request, error)) {
    sendJSON(400, "{\"error\":" + jsonString(error) + "}");
    return;
  }
  sendJSON(200, "{\"ok\":true}");
}
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
void loop() {
  if (Serial.available()) {
    const char command = Serial.read();
    if (command == 'T') { stopTimingSweep(); showHardwareColorTest(); }
    else if (command == 'W') { stopTimingSweep(); showHardwareWhiteTest(); }
    else if (command == 'G') { stopTimingSweep(); showHardwarePaletteTest(); }
    else if (command == 'V') { stopTimingSweep(); showHardwarePurpleTest(); }
    else if (command == 'H') { stopTimingSweep(); showHardwareTextTest(); }
    else if (command == 'C') {
      stopTimingSweep();
      applyClockDrive(clockDrive == STARTUP_TIMING.drive ? GPIO_DRIVE_CAP_3 : STARTUP_TIMING.drive);
    }
    else if (command == 'S') startTimingSweep();
    else if (command == 'F') startTimingSweep(true);
    else if (command == 'P' && timingSweepActive) {
      timingSweepPaused = !timingSweepPaused;
      timingProfileStarted = millis();
      Serial.printf("Timing sweep %s on test %c.\n", timingSweepPaused ? "paused" : "resumed",
                    timingProfiles[timingProfileIndex].id);
    }
    else if (command == 'N' && timingSweepActive) nextTimingProfile();
    else if (command == 'X') stopTimingSweep(true);
  }
  server.handleClient();
  updateWiFi();
  updateTimingSweep();
  pollModeButton();
  liveTick(timingSweepActive);
  delay(1);
}

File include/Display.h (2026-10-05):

#pragma once
#include "DisplayData.h"
#include <string>
#include <cstdio>
#include <cstring>
#include <algorithm>
namespace Display {
struct Model {
  int mode = 1, palette = 2, layout = 0, motion = 1;
  uint32_t tick = 0;
  int hour = -1, minute = 0, second = 0, day = 1, month = 1;
  bool valid = false, stale = false;
  int temperature = 0, code = 0;
  std::string city, title, subs = "--", views = "--", videos = "--", state = "loading";
};
inline const char* kind(int code) {
  if (code == 0) return "SUN";
  if (code <= 3) return "CLOUD";
  if (code == 45 || code == 48) return "FOG";
  if ((code >= 51 && code <= 67) || (code >= 80 && code <= 82)) return "RAIN";
  if ((code >= 71 && code <= 77) || code == 85 || code == 86) return "SNOW";
  return "STORM";
}
inline const Glyph& glyph(unsigned code) {
  for (const auto& g : font) if (g.code == code) return g;
  for (const auto& g : font) if (g.code == '?') return g;
  return font[0];
}
// Pixel labels use ASCII, transliterating common Latin accents from UTF-8.
inline std::string label(const std::string& input) {
  std::string out;
  for (size_t i = 0; i < input.size(); ++i) {
    unsigned char c = input[i];
    if (c < 128) { out += char(c >= 'a' && c <= 'z' ? c - 32 : c); continue; }
    unsigned cp = 0; unsigned count = 0;
    if ((c & 0xe0) == 0xc0) { cp=c&31; count=1; }
    else if ((c&0xf0)==0xe0) {cp=c&15;count=2;}
    else if ((c&0xf8)==0xf0) {cp=c&7;count=3;}
    for (unsigned j=0;j<count && i+1<input.size();++j) cp=(cp<<6)|(input[++i]&63);
    if (cp>=0xe0 && cp<=0xfe) cp-=32;
    if (cp>=0xc0 && cp<=0xc5) out+='A';
    else if(cp==0xc7) out+='C';
    else if(cp>=0xc8 && cp<=0xcb) out+='E';
    else if(cp>=0xcc && cp<=0xcf) out+='I';
    else if(cp==0xd1) out+='N';
    else if(cp>=0xd2 && cp<=0xd6) out+='O';
    else if(cp>=0xd9 && cp<=0xdc) out+='U';
    else if(cp==0xdd) out+='Y';
    else out+='?';
  }
  return out;
}
inline int width(const std::string& text, int scale=1) {
  int w=0; for (unsigned char c : text) w+=(glyph(c).width+1)*scale;
  return text.empty()?0:w-scale;
}
template<class Canvas> class Painter {
  Canvas& c;
public:
  explicit Painter(Canvas& canvas):c(canvas){}
  void rect(int x,int y,int w,int h,uint32_t colour) { c.rect(x,y,w,h,colour); }
  void text(const std::string& t,int x,int y,int scale,uint32_t colour) {
    for (unsigned char ch : t) {
      const auto& g=glyph(ch);
      for(int row=0;row<5;++row) for(int col=0;col<g.width;++col)
        if(g.rows[row] & (1<<(g.width-1-col))) rect(x+col*scale,y+row*scale,scale,scale,colour);
      x+=(g.width+1)*scale;
    }
  }
  void centred(const std::string& t,int y,int scale,uint32_t colour) { text(t,(64-width(t,scale))/2,y,scale,colour); }
  void ticker(const std::string& input,int y,uint32_t colour,const Model& m) {
    const std::string t=label(input); const int w=width(t);
    if(w<=60) {centred(t,y,1,colour); return;}
    if(m.motion==0) {text(t.substr(0,15),2,y,1,colour);return;}
    // Hold at the start, then scroll pixel-by-pixel, followed by a short gap.
    int offset=int(m.tick/(m.motion==2?110:180))%(w+20+12)-12;
    offset=std::max(0,offset);
    text(t,2-offset,y,1,colour);text(t,2-offset+w+20,y,1,colour);
  }
  void icon(const char* name,int x,int y,int motion,uint32_t tick,uint32_t fg,uint32_t accent) {
    const int p=motion?int(tick/(motion==2?150:300))%8:0;
    if(!strcmp(name,"SUN")) {
      rect(x+5,y+5,7,7,accent);rect(x+7,y+1,3,2,accent);rect(x+7,y+14,3,2,accent);
      rect(x+1,y+7,2,3,accent);rect(x+14,y+7,2,3,accent);
      if(motion==2 && p%2) {rect(x+2,y+2,2,2,accent);rect(x+13,y+13,2,2,accent);} return;
    }
    if(!strcmp(name,"FOG")) {for(int r=0;r<3;++r)rect(x+2+(p+r)%2,y+4+r*4,12,1,fg);return;}
    rect(x+5,y+3,7,5,fg);rect(x+2,y+6,14,5,fg);
    if(!strcmp(name,"RAIN")||!strcmp(name,"STORM")) {
      for(int r=0;r<3;++r)rect(x+3+r*5,y+12+(p+r*2)%4,1,2,accent);
      if(!strcmp(name,"STORM")){rect(x+9,y+10,2,4,accent);rect(x+7,y+13,3,2,accent);}
    } else if(!strcmp(name,"SNOW")) {for(int r=0;r<3;++r)rect(x+3+r*5,y+12+(p+r)%4,2,2,accent);}
  }
  void render(const Model& m) {
    const auto* palette=palettes[m.palette];const uint32_t fg=palette[1],accent=palette[2];
    rect(0,0,64,32,palette[0]);
    if(m.mode==1) {
      char time[8]="--:--";
      if(m.hour>=0)snprintf(time,sizeof(time),"%02d:%02d",m.hour,m.minute);
      const int y=m.layout?3:8;centred(time,y,3,fg);
      if(m.hour>=0 && m.motion && m.second%2)rect((64-width(time,3))/2+24,y,3,15,palette[0]);
      if(m.layout) {char date[8];snprintf(date,sizeof(date),"%02d/%02d",m.day,m.month);centred(m.hour<0?"SYNC":date,25,1,accent);}
      else {rect(2,28,60,1,0x18202a);if(m.hour>=0)rect(2,28,(m.second+1),1,accent);}
      if(m.motion==2 && m.hour>=0)rect((m.tick/120)%64,0,1,1,accent);
      return;
    }
    if(!m.valid) {
      centred(m.mode==2?"WEATHER":"YOUTUBE",3,1,accent);
      centred("--",11,2,fg);
      const char* status=m.state=="unconfigured"?"ADD KEY":m.state=="error"?"CHECK WEB":"LOADING";
      centred(status,25,1,accent);return;
    }
    if(m.mode==2) {
      char temp[8];snprintf(temp,sizeof(temp),"%d",m.temperature);
      if(!m.layout) {
        icon(kind(m.code),1,2,m.motion,m.tick,fg,accent);
        int scale=width(temp,3)<=35?3:2;const int w=width(temp,scale);
        text(temp,22+(36-w)/2,3,scale,fg);rect(60,3,2,2,accent);
      } else {
        centred(temp,1,3,fg);centred(kind(m.code),19,1,accent);
      }
      ticker(m.city,26,fg,m);
    } else {
      const int slide=m.layout?0:int(m.tick/5000)%3;
      const std::string value=slide==0?m.subs:slide==1?m.views:m.videos;
      const char* names[]={"SUBSCRIBERS","VIEWS","VIDEOS"};
      centred(names[slide],1,1,accent);
      const int scale=width(value,3)<=60?3:2;
      centred(value,10,scale,fg);ticker(m.title,27,accent,m);
      if(!m.layout)for(int i=0;i<3;++i)rect(26+i*5,7,3,1,i==slide?accent:0x18202a);
    }
    if(m.stale)rect(62,0,2,2,0xffb040);
  }
};
}

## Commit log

2026-10-03 Fix HUB75 brightness table depth for sprite colours
    [main.cpp]
2026-10-03 Correct green and blue channels on the HUB75 panel
    [main.cpp]
2026-10-03 Add Crystal GIF gallery with synchronized Pokemon cries over Bluetooth
    [partitions.csv]
2026-10-03 Separate Pokémon gallery, cries, and Bluetooth so main stays a modular panel controller.
    The full Pokémon interface remains on the pokemon branch. Main keeps the HUB75 connection, brightness, Wi-Fi setup, and generic text, image, GIF, and drawing controls.
    [partitions.csv]
2026-10-05 feat : cleanup and add 3d
    [bezel.stl, body.stl, bridge.stl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]
2026-10-05 Complete enclosure kits and add minimal two-part frame
    [bezel.stl, board_gauge.stl, coupon.stl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]
